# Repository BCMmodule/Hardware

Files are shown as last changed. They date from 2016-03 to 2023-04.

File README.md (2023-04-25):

# [BCM1 and BCS1](https://bcm-module.com)
Design and Document files for the BCMmodules BCM1 and BCS1 based on BeagleBone Black from [BeagleBoard.org](http://beagleboard.org). Please check out our [FAQ](https://github.com/BeagleCore/Hardware/wiki/FAQ) for questions and answers.

## BCM1 Contents
- Altium library
- Assembly Drawings
- BOM
- Footprint Drawing
- Gerber files
- Pick & Place
- Schematic Prints
- Step file
- System Reference Manual

## BCS1 Contents
- Assembly Drawings
- BOM
- Gerber files
- Pick & Place
- Schematic Prints

## General Contents
- Documentation
- Test Summary

Except where otherwise noted, licensed under a [Creative Commons Attribution-Share Alike 3.0 license](https://creativecommons.org/licenses/by-sa/3.0/). All derivative works are to be attributed to Gerald Coley of [BeagleBoard.org](http://beagleboard.org).

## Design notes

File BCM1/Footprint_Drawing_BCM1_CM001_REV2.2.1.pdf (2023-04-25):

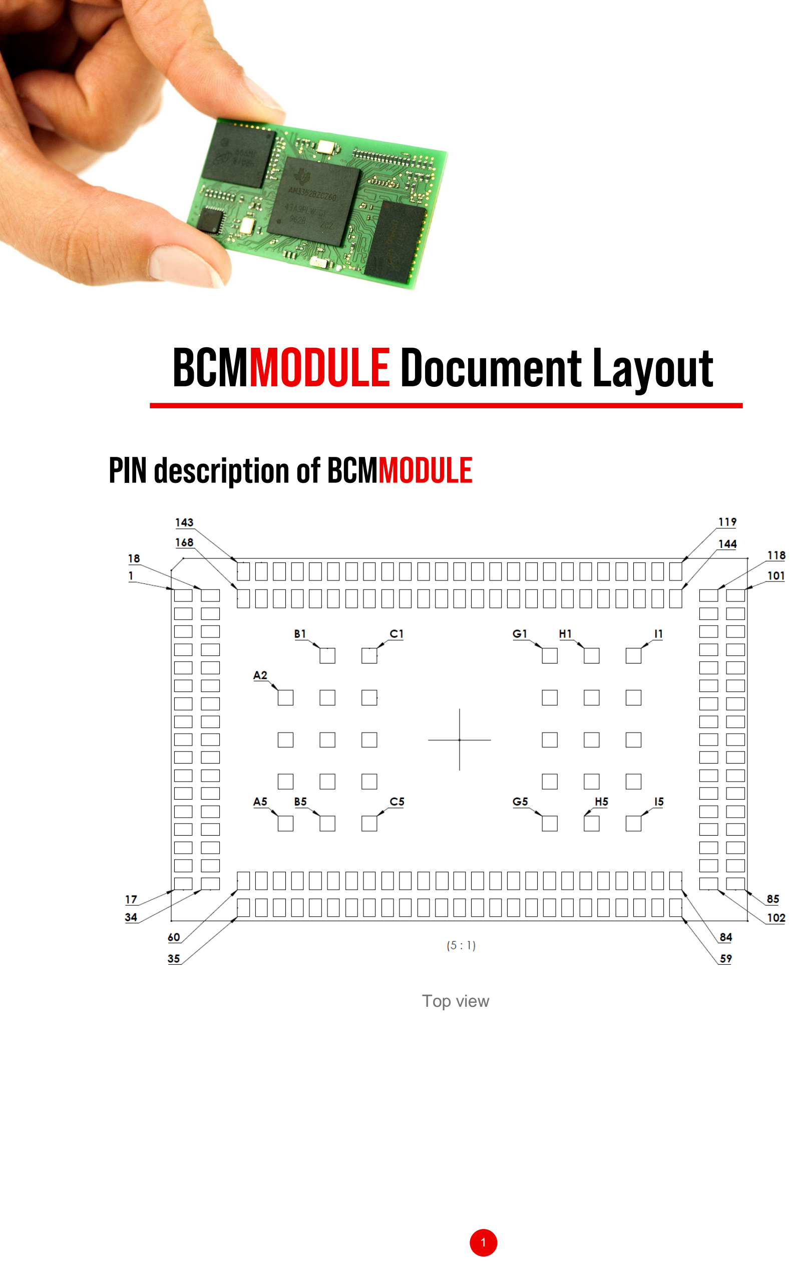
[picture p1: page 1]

1

## BCMMODULE Document Layout

PIN description of BCMMODULE

Top view

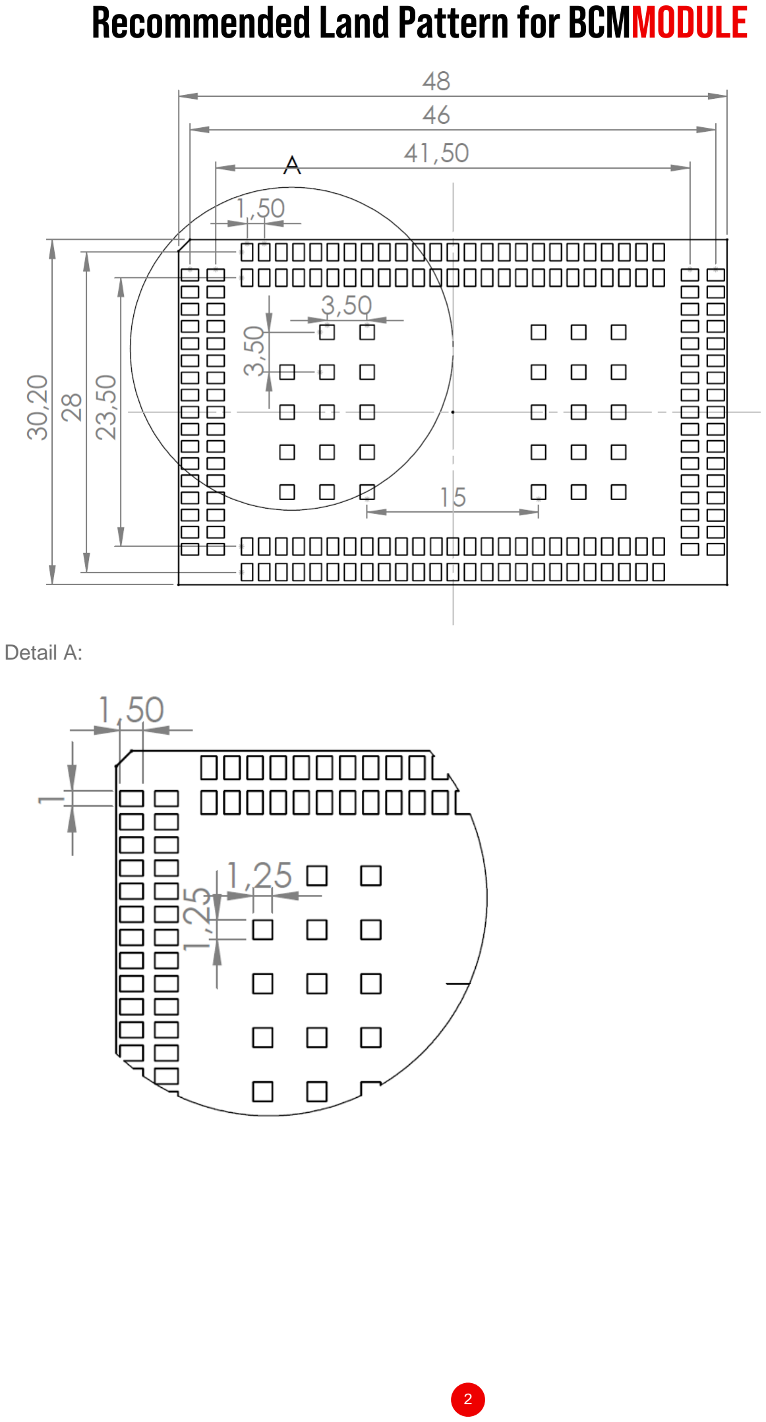
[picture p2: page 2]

2

Recommended Land Pattern for BCMMODULE

Detail A:

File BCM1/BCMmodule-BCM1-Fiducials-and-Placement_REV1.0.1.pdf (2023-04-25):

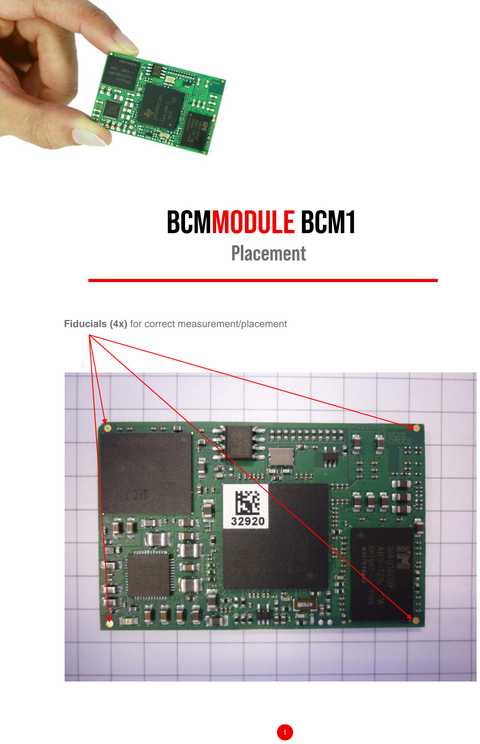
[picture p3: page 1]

# BCMMODULE BCM1

# Placement

Fiducials (4x) for correct measurement/placement

1

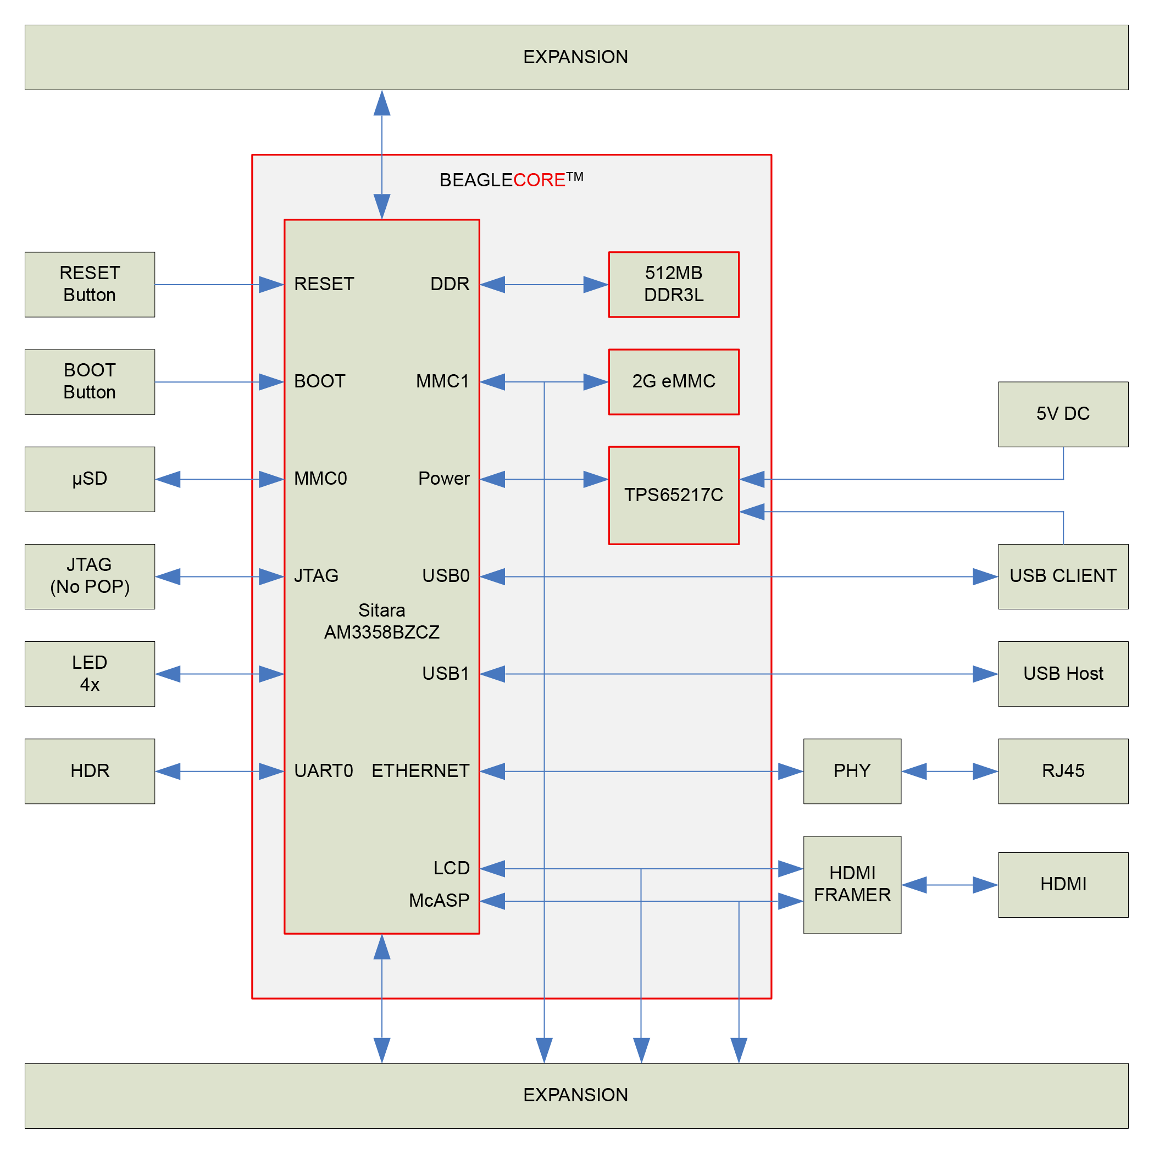
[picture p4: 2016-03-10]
BCM1/BeagleCore_BCM1_Block-Diagram.png

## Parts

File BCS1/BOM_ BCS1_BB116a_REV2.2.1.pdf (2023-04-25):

# Bill of Materials

Project: | BB116_V2.PrjPcb
Variant: | BB116a
Revision: | 2.2
Creation Date: | 21.07.2016 15:19:48
Bearbeiter: | Mierau
Art-Nr. | Quantity Designator | | Value | Description | Hersteller | Bestellbezeichnung | Footprint | S/T | Hersteller1 | Bestellbezeichnung1 | Lieferant
08.0002.0001 | 15 | C27, C29, C30, C35, C36, C131, C132, C135, C145, C147, C149, C150, C154, C155, C159 | 0.1uF/16V_02 | Capacitor 0402 16V Y5V | | | CC1005-0402 | SMD | Multicomp | MCCA000051
08.0001.0091 | 1 | C34 | 100uF/6.3V_121 0 | Capacitor 1210; 6.3V | Murata | GRM32ER60J107ME20 | CC3225-1210 | SMD
08.0001. | 2 | C133, C153 | 10uF/6V3_03 | Capacitor 0603 6V3; 10%, X5R | | | CC1608-0603 | SMD
08.0002.0011 | 1 | C134 | 1uF/10V_02 | Capacitor 0402 10V, X5R | | | CC1005-0402 | SMD
08.0002. | 1 | C136 | 470pF_02 | Capacitor 0402; 50V X7R | | | CC1005-0402 | SMD
08.0001.0055 | 1 | C141 | 22nF | Capacitor 0805; 50V; 10% | | | CC2012-0805 | SMD
08.0002.00__ | 2 | C142, C143 | 30pF/50V_02 | Capacitor 0402 50V Y5V | | | CC1005-0402 | SMD
08.0002. | 6 | C144, C146, C148, C151, C200, C201 | 2.2uF/6V3_02 | Capacitor 0402; 6V3; X5R | | | CC1005-0402 | SMD
08.0002.0___ | 16 | C156, C157, C160, C161, C162, C163, C164, C165, C166, C167, C168, C169, C170, C171, C172, C173 | 47pF/16V_02 | Capacitor 0402; 16V; X7R | | | CC1005-0402 | SMD
05.0101.00__ | 1 | D8 | RB751V40 | DIODE SCHOTTKY 40V 120MA SOD323 | NXP Semiconductors | RB751V40 | SOD323 | SMD
05.0701.0009 | 2 | DA6, DA7 | TPD4EUSB30_N P | Diode Array TVS, for USB3.0; 4fach, N und P getauscht | TI, NXP | IP4283CZ10-TBA | TPD4EUSB30 | SMD | | TPD4EUSB30DQAR
05.0701.00__ | 2 | DA9, DA10 | TPD4S012 | Diode Array TVS, for USB2.0 TypB; 4fach | TI | TPD4S012 | SON6 | SMD
04.0501.00__ | 1 | IC6 | 74LVC1G74DP | Dual D-Type Positive-Edge-Triggered Flip-Flop with Set and Reset | NXP | 74LVC1G74DP | TSSOP8 - 3x3 | SMD | | | Arrow
04.0601.00__ | 1 | IC8 | TPS2051B | Current-Limited PowerSwitch | ti | TPS2051BDGNR | DGN-MSOP8+1 | SMD
04.0601.00__ | 1 | IC11 | TDA19988 | DP to HDMI ESD, Level Shifter | NXP | TDA19988BHN/C1 | HVQFN64+EP_N | SMD
04.0601.00__ | 1 | IC14 | LAN8710A | Small Footprint MII/RMII 10/100 Ethernet Transceiver with HP Auto-MDIX and flexPWR® Technology | SMSC-Microchip | LAN8710A-EZK | QFN32+EP | SMD
04.0501.0041 | 1 | IC15 | 74LVC2G241DP | dual buffer/line driver; 3-state, 5V-tolerant | NXP | 74LVC2G241DP | TSSOP8 - 3x3 | SMD | | | Arrow
12.0501. | 4 | L3, L4, L7, L8 | 150L | Inductor 120 Ohm Ferrite 0805, 800mA | Laird-Signal Integrity Products | LI0805H151R-10 | CR2012-0805 | SMD | | | digikey,
12.0501.0011 | 2 | L5, L6 | WE-CNS-W | Stromkomp. Datenleitungsfilter WE-CNS-W, 90 Ohm | Würth Elektronik | 744231091 | WE-CNS_W -0805 | SMD | Murata | DLW21SN900SQ2L
22.07.2016 | Seite 1

# BCMMODULE

05.0401.0022 | 5 | LD1, LD2, LD3, LD4, LD5 | LEDgn_b_03 | Leuchtdiode bright grün 0603, RV(5mA)@3V3= 100OHM | Würth Elektronik | 150060VS75000 | CD1608-0603 | SMD | | | Würth Elektronik
| 6 | PM1, PM2, PM3, PM4, PM5, PM6 | PMR | Passer Markierung rund | | | PASSER_RUND
12.0601.00__ | 1 | Q3 | 25.0006MHz_CM 3225 | Quarz 25.0006MHz; CM3225 | Comtec Crystal | CM3225- 25.0006MHz | QUARZ CM3225 | SMD | Geyer | CM3225- 25.0006MHz | Comtec Crystal, Geyer
12.0601. | 1 | QO4 | 24.576MHz-V96 | Quarz Oszillator 24.576MHz; KXO-V96 | Geyer | KXO-V96 24.576MHz | QUARZ KXO-V96 | SMD | | | Geyer
09.0002. | 5 | R12, R71, R72, R73, R74 | 820R_02 | Resistor 0402 | | | CR1005-0402 | SMD
09.0002.0002 | 15 | R19, R20, R46, R47, R48, R49, R50, R51, R96, R137, R142, R149, R159, R160, R161 | 0R_02 | Resistor 0402 | | | CR1005-0402 | SMD
09.0002.0014 | 2 | R21, R167 | 33R_02 | Resistor 0402 | | | CR1005-0402 | SMD
09.0002.0017 | 3 | R23, R24, R25 | 4k75_02 | Resistor 0402 | | | CR1005-0402 | SMD
09.0002.0012 | 1 | R45 | 22R_02 | Resistor 0402 | | | CR1005-0402 | SMD
09.0002.0004 | 19 | R52, R53, R115, R116, R117, R118, R135, R145, R146, R147, R148, R150, R151, R152, R153, R154, R155, R157, R158 | 10k_02 | Resistor 0402 | | | CR1005-0402 | SMD
09.0001.0013 | 11 | R75, R125, R126, R127, R128, R129, R131, R133, R134, R138, R139 | 100R_02 | Resistor 0402 1% | | | CR1005-0402 | SMD
09.0002.00__ | 4 | R112, R113, R114, R119 | 1k5_02 | Resistor 0402 1/16W 1% | | | CR1005-0402 | SMD
09.0002.0016 | 4 | R120, R121, R122, R123 | 49R9_02 | Resistor 0402 | | | CR1005-0402 | SMD
09.0001.0158 | 2 | R130, R132 | 1k2_03_1% | Resistor 0603; 1% 1/16W | | | CR1608-0603 | SMD
09.0002.0015 | 1 | R141 | 1M_02 | Resistor 0402 | | | CR1005-0402 | SMD
09.0002.00__ | 1 | R143 | 10R_02 | Resistor 0402 | | | CR1005-0402 | SMD
09.0001.01__ | 1 | R144 | 12k1_02 | Resistor 0402; 1% | | | CR1005-0402 | SMD
09.0001.0286 | 1 | R163 | 0.02R_05 | Resistor Bauform 0805; 5% 1/4W; | | | CR2012-0805 | SMD
09.0002.0003 | 1 | R165 | 100k_02 | Resistor 0402 | | | CR1005-0402 | SMD
09.0002.0011 | 1 | R166 | 26k7_02 | Resistor 0402 | | | CR1005-0402 | SMD
99.0000.0___ | 1 | RT1 | MF-MSMF010 | resettable Fuse MF_MSMF 30V, 0,2A bei 23°C | BOURNS | MF-MSMF010 | FUSE-MF-MSMF | SMD
06.0001.00__ | 2 | T1, T2 | DDC114YU | 2 fach NPN m Widerständen Vceo=40V, Ic=0.1A | Rohm | DDC114YU | SOT363 | SMD
10.0100.00__ | 3 | TA1, TA2, TA3 | TA_C&K_KMR23 1 | Taster smd 1pol mm pitch, 4.6x2.8mm case | C&K | KMR231GLFS | TA_KMR2 | SMD
03.0100.0158 | 1 | XB3 | USB_R_WE | USB einfach RA Type A | Würth | 61400416021 | 61400416021 | THT | | | Würth
| 1 | XB4 | MINI-USB_B | USB MINI Typ B einfach 5pol. | Molex | 0513870530 | USB-MINI-B | SMD

03.0100.0301 | 1 | XB5 | J00-0065NL;RJ45+Ü +L | Buchse RJ45 mit Übertrager und LEDS | Pulse, Würth | J00-0065NL | RJ45+Ü+L | THT | 7499010211A
03.0101.00__ | 1 | XB6 | Micro-HDMI_Buchse_T ype D | micro HDMI Buchse SMT Type D | fci | 10118241-001RLF | Micro_HDMI_FCI_ SMT_Type D | SMT
0..0000.0... | 2 | XB8, XB9 | B2X23_THT | Buchsenleiste 46pol. IDC, vertikal 2.54mm pitch | Sullins Connector Solutions | PPPC232LFBN-RC | BU2X23 | THT | | Digi Key; S7126-ND,
03.0101.00.. | 1 | XB10 | MICRO SD_ALPS_R | MICRO SD Memory card connector push/push reverse mount ALPS (SCHA5B0200) | ALPS | SCHA5B0200 | Micro-SD-Card-Reverse Mount Conn-ALPS- | SMD
03.0__0.00__ | 1 | XS1 | ST1x2_PJ | DC-Power-Jack, 2mm Stift, 5A, THT,gew. | CUI | PJ-002AH | ST1X2THT-2mm-DC_WA | THT

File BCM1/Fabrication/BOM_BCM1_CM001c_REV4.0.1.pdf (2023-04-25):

# Bill of Materials

Project: | CM001_V4.PrjPcb
Variant: | CM001c
Revision: | 4.0
Creation Date: | 07.09.2018 14:06:05
Bearbeiter: | Mierau
Art-Nr. | QuanDesignator | | Value | Description | Hersteller | Bestellbezeichnung | Footprint | S/T | Hersteller1 | Bestellbezeichnung1 | Lieferant
08.0001.0___ | 23 | C1, C2, C4, C7, C8, C9, C10, C11, C12, C13, C14, C15, C39, C40, C41, C55, C62, C77, C95, C96, C118, C122, C126 | 10uF_03_10V_X 7R | Capacitor 0603 10uF 10V X7R | | | CC1608-0603 | SMD
08.0002.0___ | 82 | C3, C20, C28, C31, C33, C37, C38, C42, C43, C44, C45, C46, C47, C48, C49, C50, C51, C52, C53, C54, C56, C57, C58, C59, C60, C61, C63, C64, C65, C66, C67, C68, C69, C70, C71, C72, C73, C74, C75, C76, C78, C79, C80, C81, C82, C83, C84, C85, C86, C87, C88, C92, C93, C94, C97, C98, C99, C100, C101, C102, C103, C105, C107, C108, C109, C110, C111, C112, C113, C114, C115, C116, C117, C119, C120, C121, C124, C127, C128, C129, C130, C158

0.1uF/6V3_01_X
7R
Capacitor 0201 6,3V X7R | any | CC0603-0201 | SMD
08.0002. | 4 | C16, C18, C24, C125 | 2.2uF/6V3_02_X 7R | Capacitor 0402 6V3 X7R | CC1005-0402 | SMD
08.0002.___ | 1 | C17 | 2.2uF/10V_02_X 7R | Capacitor 0402 10V X7R | CC1005-0402 | SMD
08.0002. | 1 | C19 | 470pF_02 | Capacitor 0402 50V X7R | CC1005-0402 | SMD
08.0002.0037 | 4 | C21, C22, C25, C26 | 18pF_02 | Capacitor 0402 50V NPO | CC1005-0402 | SMD
08.0002.0009 | 2 | C32, C123 | 1nF/50V_02 | Capacitor 0402 X7R 50V | CC1005-0402 | SMD
08.0002.0030 | 3 | C89, C90, C91 | 1uF/10V_01 | Capacitor 0201 10V X6S | CC0603-0201 | SMD
08.0002.0011 | 1 | C104 | 1uF/10V_02 | Capacitor 0402 10V X5R | CC1005-0402 | SMD

# BCMMODULE

08.0002.0041 | 1 | C106 | 1uF/25V_02_X6 S | Capacitor 0402 25V X6S | | | CC1005-0402 | SMD
08.0002.0___ | 1 | C152 | 0.1uF/16V_02_X 7R | Capacitor 0402 16V X7R | | | CC1005-0402 | SMD | muRata | GCM188R70J225KE22D
04.0501.00__ | 1 | IC3 | SN74LVC1G06D CK | Single buffer/line driver, 5V-tolerant Input, Open collector, SOT353(SC70) | TI | SN74LVC1G06DCK | SOT353 | SMD | | | Arrow
04.0701. | 1 | IC5 | AM3358BZCZA1 00 | Cortex A8 Processor 15x15_industriell | Texas Instruments | AM3358BZCZA100 | BGA324_RM0.8_1 5x15 | SMD | | | digikey
04.0701. | 1 | IC7 | CAT24C32C5CT R | Serial EEPROM; 2-wire, 8192 x 8 bits | ON SEMI | CAT24C32C5CTR | WLCSP5 | SMD
04.0701.0145 | 1 | IC12 | DDR3L-800-SDRAM-4G-256Mx16_i | DDR3L 800MHz SDRAM; 4Giga 256M x 16, industrial | Intelligent Memory | IM4G16D3FABG-125I | BGA96_T9_P8_9 X14 | SMD | | | Memphis
04.0701. | 1 | IC13 | eMMC-4GB | Flash Card 4G-byte 3.3V MultiMedia Card 153-Pin WFBGA | Hynix | H26M31001HPR | BGA153_P14_P5_ 11P5X13 | SMD | Kingston | KE4CN2H5A-A58 | memphis
04.0501.0057 | 1 | IC16 | 74LVC1G07DCK | Single Buffer/Driver With Open-Drain Output SOT353 (SC70) | TI | 74LVC1G07DCK | SOT353 | SMD | | | Arrow
12.0501. | 3 | L1, L2, L3 | 2.2uH_20 | Inductor 2520; 2,2uH; 1,3A | MURATA | LQM2HPN2R2MG0L | CR9879-2520 | SMD
12.0501. | 3 | L4, L5, L6 | 150L | Inductor 150 Ohm Ferrite 0805, 800mA | Laird-Signal Integrity Products | LI0805H151R-10 | CR2012-0805 | SMD | | | digikey,
05.0401.0022 | 1 | LD1 | LEDgn_b_03 | Leuchtdiode bright grün 0603, RV(5mA)@3V3= 100OHM | Würth Elektronik | 150060VS75000 | CD1608-0603 | SMD | | | Würth Elektronik
| 4 | PM1, PM2, PM3, PM4 | PMR | Passer Markierung rund | | | PASSER_RUND
09.0002.0003 | 1 | R1 | 100k_02 | Resistor; 0402; 1% | | | CR1005-0402 | SMD
09.0002.0028 | 3 | R3, R4, R97 | 1k5_02 | Resistor; 0402; 1% | | | CR1005-0402 | SMD
09.0002.0002 | 9 | R5, R6, R7, R8, R27, R29, R30, R162, R165 | 0R_02 | Resistor; 0402; 5% | | | CR1005-0402 | SMD
09.0002.0023 | 1 | R10 | 470k_02 | Resistor; 0402; 1% | | | CR1005-0402 | SMD
09.0002. | 1 | R11 | 280k_02 | Resistor; 0402; 1% | | | CR1005-0402 | SMD
09.0002. | 1 | R12 | 820R_02 | Resistor; 0402; 1% | | | CR1005-0402 | SMD
09.0002.0004 | 17 | R14, R54, R96, R98, R100, R101, R102, R103, R104, R105, R106, R107, R108, R109, R110, R111, R156 | 10k_02 | Resistor; 0402; 1% | | | CR1005-0402 | SMD
09.0002.0015 | 1 | R17 | 1M_02 | Resistor; 0402; 1% | | | CR1005-0402 | SMD
09.0002.0014 | 2 | R18, R28 | 33R_02 | Resistor; 0402; 1% | | | CR1005-0402 | SMD
09.0002.0016 | 1 | R22 | 49R9_02 | Resistor; 0402; 1% | | | CR1005-0402 | SMD
09.0002.0017 | 3 | R26, R163, R164 | 4k75_02 | Resistor; 0402; 1% | | | CR1005-0402 | SMD
09.0002.0070 | 16 | R57, R65, R66, R67, R68, R80, R82, R83, R84, R85, R86, R87, R88, R89, R94, R95 | 100k_01 | Resistor 0201, 1/20W | | | CR0603-0201 | SMD
09.0002.0071 | 1 | R99 | 240R_02 | Resistor; 0402; 1% | | | CR1005-0402 | SMD
04.0901. | 1 | SR1 | TPS65217DRSL | TPS65217x Single-Chip PMIC for Battery-Powered Systems | TI | TPS65217DRSL | RSL48+1_TI_TPS | SMD
04.0901. | 1 | SR2 | TL5209 | IC LDO VOLT REG 500MA 8-SOIC | TI | TL5209DR | SO8 | SMD | | | Arrow

12.0601.00__ | 1 | Y1 | 32.768kHz_i | Quarz; 3,2x1,5mm, -40°C bis 85°C | Epson | FC-135 32.7680KA-A3 | CM3215 | SMD
12.0601.0029 | 1 | Y2 | 24MHz_CM3225 _i | Quarz; 3,2x2,5mm, 20pF, -40°C bis 85°C | Fox Electronics | FQ3225BR-24.000 | QUARZ CM3225 | SMD | Comtec Crystals | A024000000CIFBPN43D B | Digikey

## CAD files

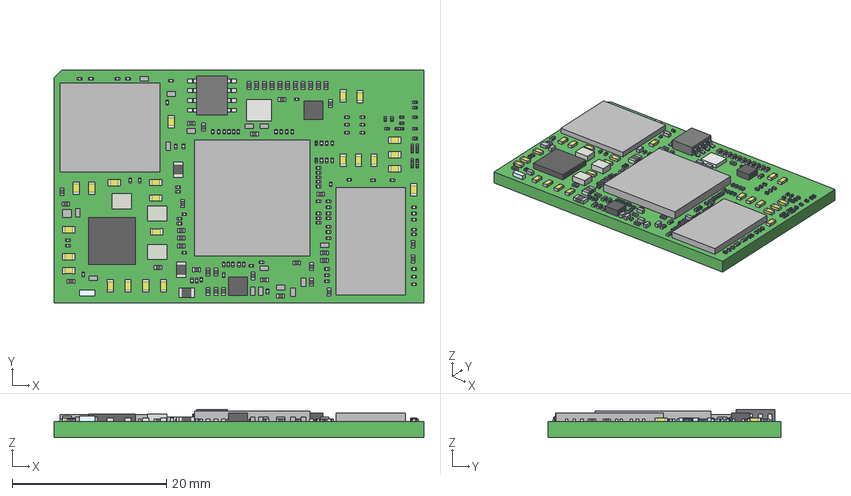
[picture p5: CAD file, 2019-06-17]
BCM1/Fabrication/BCM1_CM001_REV4.0.step
48.0 x 30.2 x 3.69 mm
Extruded x 373
CR_0402 x 42
CR_0805 x 3
CC_0603 x 23

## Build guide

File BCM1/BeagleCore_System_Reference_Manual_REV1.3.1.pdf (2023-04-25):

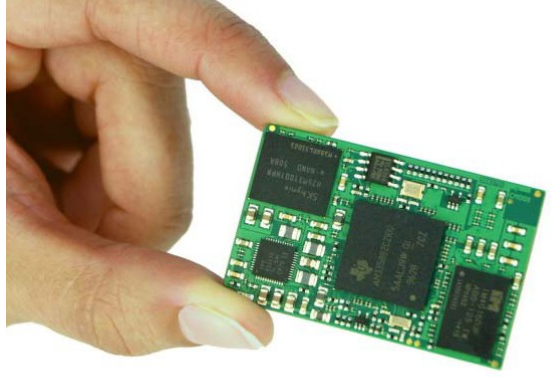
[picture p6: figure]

BCMMODULE BCM1 | 1

# BCMMODULE BCM1

# System Reference Manual

### Revision 1.3

# Disclaimer

The design materials referred to in this document are based on the BeagleBone Black and are neither supported nor do they constitute a reference design. If you are looking for support, please join the BeagleBoard Community over at BeagleBoard.org/discuss.

There is no warranty for the design materials, to the extent permitted by applicable law. Except when otherwise stated in writing the copyright holders and/or other parties provide the design materials “as is” without warranty of any kind, either expressed or implied, including, but not limited to, the implied warranties of merchantability and fitness for a particular purpose. The entire risk as to the quality and performance of the design materials is with you. In no event shall the authors or copyright holders be liable for any claim,
damages or other liability, whether in an action of contract, tort or otherwise, arising from, out of or in connection with the design material or the use or other dealings in the design materials. Should the design materials prove defective, you assume the cost of all necessary servicing, repair or correction.

The user assumes all responsibility and liability for proper and safe handling of the goods. Further, the user indemnifies BCMmodule from all claims arising from the handling or use of the goods. Due to the open construction of the product, it is the user’s responsibility to take any and all appropriate precautions with regard to electrostatic discharge.

Except to the extent of the indemnity set forth above, neither party shall be liable to the other for any indirect, special, incidental, or consequential damages. BCMmodule currently deals

2

with a variety of customers for products, and therefore our arrangement with the user is not exclusive. BCMmodule assumes no liability for applications assistance, customer product design, software performance, or infringement of patents or services described herein.

Please read the System Reference Manual and, specifically, the Warnings and Restrictions notice in the User’s Guide prior to handling the product. This notice contains important safety information about temperatures and voltages.

For additional information, please visit bcm-module.com.

Postal Address:

## iesy GmbH

Darmcher Grund 22
58540 Meinerzhagen
Germany

# Introduction

This document is the System Reference Manual for BCM1. It is intended as a guide to assist anyone purchasing or who are considering purchasing the board to understand the overall system design and the features of the BCM1. It can also be used as a reference for the design for those who are implementing this design into their own product.

This design is subject to change without notice as we will work to keep improving the design as the product matures.

This design is subject to change without notice as we will work to keep improving the design as the product matures.

# Known Issues

For an up to date list of all known issues per revision, please refer to the BCMmodule GitHub repository and the issues listed there: https://github.com/BCMmodule/Hardware/issues.

# BCMMODULE BCM1

3

# Contents

# BCMMODULE BCM1

4

# 1. What is BCMMODULE?

The BCM1 is a miniaturized computer module for industrial or commercial applications covering all core features of BeagleBone Black. It is designed to address the Open Source Community, early adopters, and anyone interested in a low cost ARM Cortex A8 based processor. It enables users to design their own embedded devices while remaining a maximum compatibility with the BeagleBone Black.

# 2. Features

This section covers the specifications of the BCM1.

### - Dimensions (WDH): 48 mm × 31 mm × 3,5 mm

### - Processor: Texas Instruments AM335x Cortex-A8 “Sitara”

### - Clock rate: 1.0GHz

### - Memory: 512 MB DDR3

### - Flash: 4 GB 8-bit eMMC

### - Temperature range: 0…60°C (optionally: -40…85°C)

- Operating: 10 to 90% r. H. non cond.
Storage: 5 to 95% r. H. non cond.

### - Supported interfaces / extensions:

### o 1 × RGMII Interface for 10/100/1000 Mbit LAN

### o 2 × USB 2.0 Host / Client

### o 1 × SDIO (for SD memory cards)

### o 1 × UART / 1 × JTAG (for debugging)

o up to 59 × GPIO for HDMI, CAN, I2C, etc.

For further details we would like to refer to the latest documentation for BeagleBone Black available at http://beagleboard.org/static/beaglebone/latest/Docs/Hardware/.

# BCMMODULE BCM1

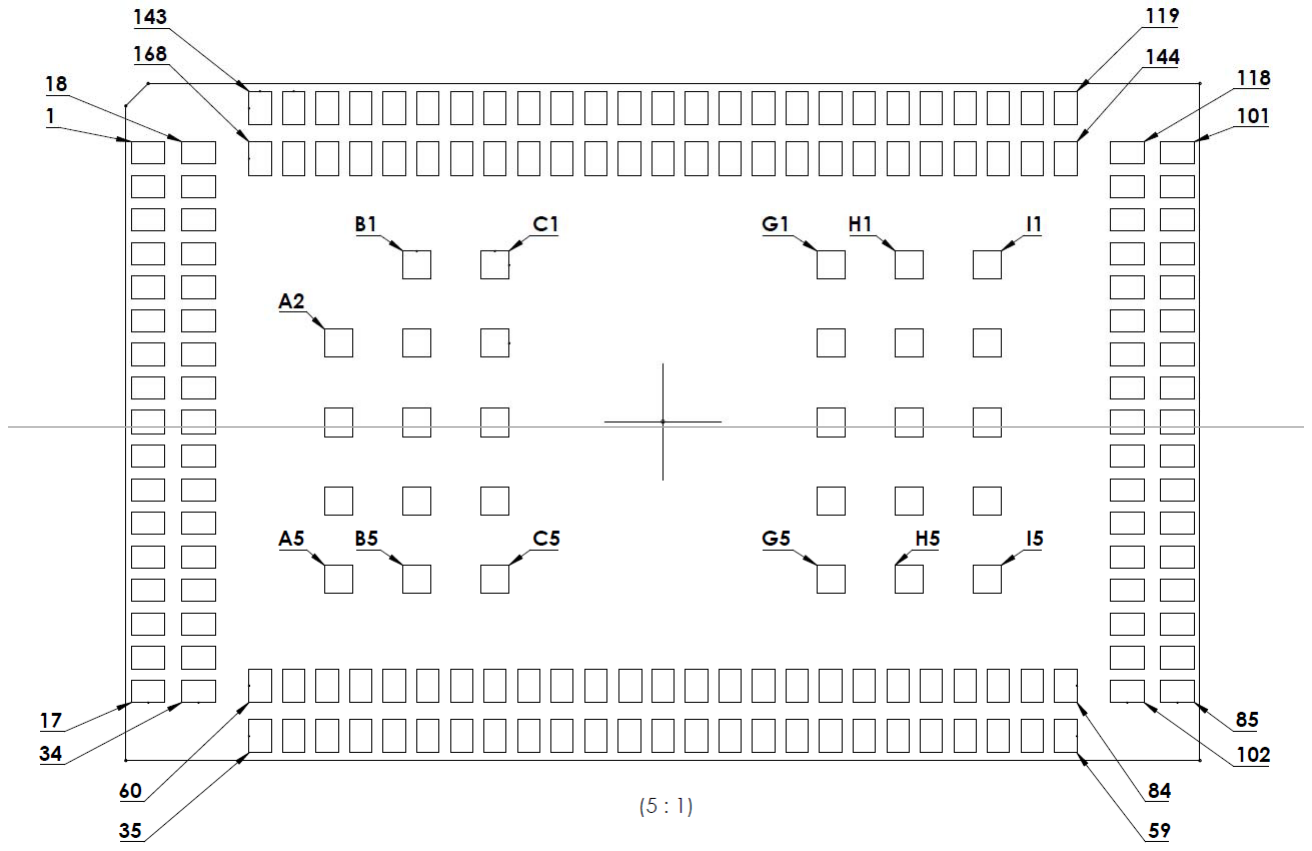
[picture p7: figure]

5

# 3. Specifications

# 3.1 Pin-signals Graphic Overview

This section covers the pin-signals of the BCM1 and provides descriptions of the major components and interfaces that make up the BCM1.

Img. 1: Pin-signals for BCM1 (top view)

# 3.2 Pin-signals Table

# BCMMODULE BCM1

6

Pin on BGA | Transfer-Signal on BGA | from Pin AM3358BZCZ100 | from Pin TPS65217CRSLR | comment
1 | USB0_D_P | N17
2 | USB0_D_N | N18
3 DGND
4 | MII1_RXD2 | L16 | | GMII1_RXD2/UART3_TXD/RGMII1_RD2/MMC0_DAT4/MMC1_DAT3/ UART1_RIN/MCASP0_AXR1/GPIO2_19
5 | MII1_RXD3 | L17 | | GMII1_RXD3/UART3_RXD/RGMII1_RD3/MMC0_DAT5/MMC1_DAT2/ UART1_DTRN/MCASP0_AXR0/GPIO2_18
6 | MII1_RXCLK | L18 | | GMII1_RXCLK/UART2_TXD/RGMII1_RCLK/MMC0_DAT6/MMC1_DAT1/ UART1_DSRN/MCASP0_FSX/GPIO3_10
7 | MII1_TXD1 | K16 | | GMII1_TXD1/RMII1_TXD1/RGMII1_TD1/MCASP1_FSR/MCASP1_AXR1/ EQEP0A_IN/MMC1_CMD/GPIO0_21
8 | MII1_TXD3 | J18 | | GMII1_TXD3/DCAN0_TX/RGMII1_TD3/UART4_RXD/MCASP1_FSX/ MMC2_DAT1/MCASP0_FSR/GPIO0_16
9 | MII1_RXDV | J17 | | GMII1_RXDV/LCD_MEMORY_CLK/RGMII1_RCTL/UART5_TXD/ MCASP1_ACLKX/MMC2_DAT0/MCASP0_ACLKR/GPIO3_4
10 | MII1_TXEN | J16 | | GMII1_TXEN/RMII1_TXEN/RGMII1_TCTL/TIMER4/MCASP1_AXR0/ EQEP0_INDEX/MMC2_CMD/GPIO3_3
11 | MII1_REFCLK | H18 | | RMII1_REFCLK/XDMA_EVENT_INTR2/SPI1_CS0/UART5_TXD/ MCASP1_AXR3/MMC0_POW/MCASP1_AHCLKX/GPIO0_29
12 | MII1_COL | H16 | | GMII1_COL/RMII2_REFCLK/SPI1_SCLK/UART5_RXD/MCASP1_AXR2/ MMC2_DAT3/MCASP0_AXR2/GPIO3_0
13 | BKL_ISET2 | | 36
14 | BKL_ISET1 | | 35
15 | BKL_L4 | | 37
16 | BKL_FB_WLED | | 38
17 DGND
18 DGND
19 | MDIO_DATA | M17 | | MDIO_DATA/TIMER6/UART5_RXD/UART3_CTSN/MMC0_SDCD/ MMC1_CMD/MMC2_CMD/GPIO0_0
20 | MDIO_CLK | M18 | | MDIO_CLK/TIMER5/UART5_TXD/UART3_RTSN/MMC0_SDWP/ MMC1_CLK/MMC2_CLK/GPIO0_1
21 | MII1_RxD0 | M16 | | GMII1_RXD0/RMII1_RXD0/RGMII1_RD0/MCASP1_AHCLKX/ MCASP1_AHCLKR/MCASP1_ACLKR/MCASP0_AXR3/GPIO2_21
22 | MII1_RxD1 | L15 | | GMII1_RXD1/RMII1_RXD1/RGMII1_RD1/MCASP1_AXR3/MCASP1_FSR/ EQEP0_STROBE/MMC2_CLK/GPIO2_20

# BCMMODULE BCM1

7

Pin on BGA | Transfer-Signal on BGA | from Pin AM3358BZCZ100 | from Pin TPS65217CRSLR | comment
23 | MII1_TXCLK | K18 | | GMII1_TXCLK/UART2_RXD/RGMII1_TCLK/MMC0_DAT7/MMC1_DAT0/ UART1_DCDN/MCASP0_ACLKX/GPIO3_9
24 | MII1_TxD0 | K17 | | GMII1_TXD0/RMII1_TXD0/RGMII1_TD0/MCASP1_AXR2/ MCASP1_ACLKR/EQEP0B_IN/MMC1_CLK/GPIO0_28
25 | MII1_TxD2 | K15 | | GMII1_TXD2/DCAN0_RX/RGMII1_TD2/UART4_TXD/MCASP1_AXR0/ MMC2_DAT2/MCASP0_AHCLKX/GPIO0_17

26 DGND
27 | MII1_RXERR | J15 | | GMII1_RXERR/RMII1_RXERR/SPI1_D1/I2C1_SCL/MCASP1_FSX/ UART5_RTSN/UART2_TXD/GPIO3_2
28 | MII1_CRS_DV | H17 | | GMII1_CRS/RMII1_CRS_DV/SPI1_D0/I2C1_SDA/MCASP1_ACLKX/ UART5_CTSN/UART2_RXD/GPIO3_1

29 DGND
30 | BKL_ISINK2 | | 33
31 | BKL_ISINK1 | | 34
32 | I2C0_SCL | C16 | 28 | I2C0_SCL/TIMER7/UART2_RTSN/ECAP1_IN_PWM1_OUT////GPIO3_6
33 | I2C0_SDA | C17 | 27 | I2C0_SDA/TIMER4/UART2_CTSN/ECAP2_IN_PWM2_OUT////GPIO3_5
34 DGND
35 | UART4_TXD | U17 | GPMC_WPN/GMII2_RXERR/GPMC_CSN5/RMII2_RXERR/MMC2_SDCD/ PR1_MDIO_MDCLK/UART4_TXD/GPIO0_31
36 | UART4_RXD | T17 | GPMC_WAIT0/GM112_CRS/GPMC_CSN4/RMII2_CRS_DV/ MMC1_SDCD/PR1_MII1_RXDV/UART4_RXD/GPIO0_30
37 | GPIO1_28 | U18 | GPMC_BE1N/GMII2_COL/GPMC_CSN6/MMC2_DAT3/GPMC_DIR/ PR1_MII1_RXLINK/MCASP0_ACLKR/GPIO1_28
38 | EHRPWM1A | U14 | GPMC_A2/GMII2_TXD3/RGMII2_TD3/MMC2_DAT1/GPMC_A18/ PR1_MII1_TXD2/EHRPWM1A/GPIO1_18
39 | EHRPWM1B | T14 | GPMC_A3/GMII2_TXD2/RGMII2_TD2/MMC2_DAT2/GPMC_A19/ PR1_MII1_TXD1/EHRPWM1B/GPIO1_19
40 | MMC0_DAT3 | F17 | MMC0_DAT3/GPMC_A20/UART4_CTSN/TIMER5/UART1_DCDN/ PR1_PRU0_PRU_R30_8/PR1_PRU0_PRU_R31_8/GPIO2_26
41 | MMC0_DAT1 | G15 | MMC0_DAT1/GPMC_A22/UART5_CTSN/UART3_RXD/UART1_DTRN/ PR1_PRU0_PRU_R30_10/PR1_PRU0_PRU_R31_10/GPIO2_28
42 | MMC0_CD | C15 | SPI0_CS1/UART3_RXD/ECAP1_IN_PWM1_OUT/MMC0_POW/ XDMA_EVENT_INTR2/MMC0_SDCD/EMU4/GPIO0_60

# BCMMODULE BCM1

8

Pin on BGA | Transfer-Signal on BGA | from Pin AM3358BZCZ100 | from Pin TPS65217CRSLR | comment
43 XDMA_EVENT_INT | R0 | A15 | | EVENT_INTR0/TIMER4/CLKOUT1/SPI1_CS1/PR1PRU1R31_16/EMU2/ GPIO0_19
44 | UART0_CTS# | E18 | | Reserved for future use
45 | UART0_RTS# | E17 | | Reserved for future use
46 | UART0_TX | E16 | | UART0_TXD/SPI1_CS1/DCAN0_RX/I2C2_SCL/ECAP1_IN_PWM1_OUT/ PR1_PRU1_PRU_R30_15/PR1_PRU1_PRU_R31_15/GPIO1_11
47 | UART0_RX | E15 | | UART0_RXD/SPI1_CS0/DCAN0_TX/I2C2_SDA/ECAP2_IN_PWM2_OUT/ PR1_PRU1_PRU_R30_14/PR1_PRU1_PRU_R31_14/GPIO1_10
48 | SYS_RESETn | A10
49 | I2C1_SDA | B16 | | SPI0_D1/MMC1_SDWP/I2C1_SDA/EHRPWM0_TRIPZONE_INPUT/ PR1_UART0_RXD/PR1_EDIO_DATA_IN0/PR1_EDIO_DATA_OUT0/GPIO0_4
50 | I2C1_SCL | A16 | | SPI0_CS0/MMC2_SDWP/I2C1_SCL/EHRPWM0_SYNCI_O/ PR1_UART0_TXD/PR1_EDIO_DATA_IN1/PR1_EDIO_DATA_OUT1/GPIO0_5
51 | JTAG_EMU1 | B14
52 | JTAG_TCK | A12
53 | JTAG_TDO | A11
54 | JTAG_TRSTn | B10
55 | GNDA_ADC | A9
56 | AIN6 | A8
57 | AIN4 | C8
58 | AIN2 | B7
59 | AIN0 | B6
60 | BAT1 | | 4, 5
61 | BAT_SENSE | | 6
62 | BAT_TS | | 11
63 | PWR_BUT | | 25
64 | MMC0_CMD | G18 | | MMC0_CMD/GPMC_A25/UART3_RTSN/UART2_TXD/DCAN1_RX/ PR1_PRU0_PRU_R30_13/PR1_PRU0_PRU_R31_13/GPIO2_31
65 | MMC0_CLKO | G17 | | MMC0_CLK/GPMC_A24/UART3_CTSN/UART2_RXD/DCAN1_TX/ PR1_PRU0_PRU_R30_12/PR1_PRU0_PRU_R31_12/GPIO2_30
66 | MMC0_DAT2 | F18 | | MMC0_DAT2/GPMC_A21/UART4_RTSN/TIMER6/UART1_DSRN/ PR1_PRU0_PRU_R30_9/PR1_PRU0_PRU_R31_9/GPIO2_27

# BCMMODULE BCM1

9

Pin on BGA | Transfer-Signal on BGA | from Pin AM3358BZCZ100 | from Pin TPS65217CRSLR | comment
67 | MMC0_DAT0 | G16 | | MMC0_DAT0/GPMC_A23/UART5_RTSN/UART3_TXD/UART1_RIN/ PR1_PRU0_PRU_R30_11/PR1_PRU0_PRU_R31_11/GPIO2_29
68 | GPIO0_7SRC | C18 | | ECAP0_IN_PWM0_OUT/UART3_TXD/SPI1_CS1/ PR1_ECAP0_ECAP_CAPIN_APWM_O/SPI1_SCLK/MMC0_SDWP/ XDMA_EVENT_INTR2/GPIO0_7
69 | UART2_RXD | A17 | | SPI0_SCLK/UART2_RXD/I2C2_SDA/EHRPWM0A/PR1_UART0_CTS_N/ PR1_EDIO_SOF/EMU2/GPIO0_2
70 | UART2_TXD | B17 | | SPI0_D0/UART2_TXD/I2C2_SCL/EHRPWM0B/PR1_UART0_RTS_N/ PR1_EDIO_LATCH_IN/EMU3/GPIO0_3
71 | I2C2_SDA | D18 | | UART1_CTSN/TIMER6/DCAN0_TX/I2C2_SDA/SPI1_CS0/PR1_UART0_CTS_ N/PR1_EDC_LATCH0_IN/GPIO0_124
72 | I2C2_SCL | D17 | | UART1_RTSN/TIMER5/DCAN0_RX/I2C2_SCL/SPI1_CS1/PR1_UART0_RTS_ N/PR1_EDC_LATCH1_IN/GPIO0_13
73 | UART1_RXD | D16 | | UART1_RXD/MMC1_SDWP/DCAN1_TX/I2C1_SDA//PR1_UART0_RXD/ PR1_PRU1_PRU_R31_16/GPIO0_14
74 | UART1_TXD | D15 | | UART1_TXD/MMC2_SDWP/DCAN1_RX/I2C1_SCL//PR1_UART0_TXD/ PR1_PRU0_PRU_R31_16/GPIO0_15

75 DGND
76 | CLKOUT_SRC | D14 | | EVENT_INTR1/TCLKIN/CLKOUT2/TIMER7/PR1PRU0_PRUR31_16/ EMU3/GPIO0_20
77 | JTAG_EMU0 | C14
78 | JTAG_TDI | B11
79 | JTAG_TMS | C11
80 | GNDA_ADC | A8
81 | VDD_ADC | B9 (über R27)
82 | AIN5 | B8
83 | AIN3 | A7
84 | AIN1 | C7
85 | GPIO3_18 | B12 | MCASP0_ACLKR/EQEP0A_IN/MCASP0_AXR2/MCASP1_ACLKX/ MMC0_SDWP/PR1_PRU0_PRU_R30_4/PR1_PRU0_PRU_R31_4/GPIO3_18
86 | GPIO3_19 | C13 | MCASP0_FSR/EQEP0B_IN/MCASP0_AXR3/MCASP1_FSX/EMU2/ PR1_PRU0_PRU_R30_5/PR1_PRU0_PRU_R31_5/GPIO3_19

# BCMMODULE BCM1

10

Pin on BGA | Transfer-Signal on BGA | from Pin AM3358BZCZ100 | from Pin TPS65217CRSLR | comment
87 | GPIO3_20 | D13 | | MCASP0_AXR1/EQEP0_INDEX//MCASP1_AXR0/EMU3/ PR1_PRU0_PRU_R30_6/PR1_PRU0_PRU_R31_6/GPIO3_20
88 | GPIO3_21 | A14 | | MCASP0_AHCLKX/EQEP0_STROBE/MCASP0_AXR3/MCASP1_AXR1/ EMU4/PR1_PRU0_PRU_R30_7/PR1_PRU0_PRU_R31_7/GPIO3_21
89 | USB1_ID | P17
90 DGND
91 | USB1_D_P | R17
92 | USB1_D_N | R18
93 | USB1_Ocn | T16 | | GPMC_A10/GMII2_RXD1/RGMII2_RD1/RMII2_RXD1/GPMC_A26/ PR1_MII1_CRS/MCASP0_AXR0/GPIO1_26
94 | LCD_DATA0 | R1 | | LCD_DATA0/GPMC_A0//EHRPWM2A//PR1_PRU1_PRU_R30_0/ PR1_PRU1_PRU_R31_0/GPIO2_6
95 | LCD_DATA2 | R3 | | LCD_DATA2/GPMC_A2//EHRPWM2_TRIPZONE_INPUT// PR1_PRU1_PRU_R30_2/PR1_PRU1_PRU_R31_2/GPIO2_8
96 | LCD_DATA4 | T1 | | LCD_DATA4/GPMC_A4//EQEP2A_IN//PR1_PRU1_PRU_R30_4/ PR1_PRU1_PRU_R31_4/GPIO2_10
97 | LCD_DATA6 | T3 | | LCD_DATA6/GPMC_A6/PR1_EDIO_DATA_IN6/EQEP2_INDEX/ PR1_EDIO_DATA_OUT6/PR1_PRU1_PRU_R30_6/PR1_PRU1_PRU_R31_6/ GPIO2_12
98 | LCD_DATA8 | U1 | | LCD_DATA8/GPMC_A12/EHRPWM1_TRIPZONE_INPUT/ MCASP0_ACLKX/UART5_TXD/PR1_MII0_RXD3/UART2_CTSN/GPIO2_14
99 | LCD_DATA10 | U3 | | LCD_DATA10/GPMC_A14/EHRPWM1A/MCASP0_AXR0// PR1_MII0_RXD1/UART3_CTSN/GPIO2_16
100 | LCD_DATA12 | V2 | | LCD_DATA12/GPMC_A16/EQEP1A_IN/MCASP0_ACLKR/ MCASP0_AXR2/PR1_MII0_RXLINK/UART4_CTSN/GPIO0_8
101 | LCD_DATA14 | V4 | | LCD_DATA14/GPMC_A18/EQEP1_INDEX/MCASP0_AXR1/UART5_RXD/ PR1_MII_MR0_CLK/UART5_CTSN/GPIO0_10

102 DGND
103 | SPI1_SCLK | A13 | | MCASP0_ACLKX/EHRPWM0A//SPI1_SCLK/MMC0_SDCD/ PR1_PRU0_PRU_R30_0/PR1_PRU0_PRU_R31_0/GPIO3_14
104 | SPI1_D0 | B13 | | MCASP0_FSX/EHRPWM0B//SPI1_D0/MMC1_SDCD/ PR1_PRU0_PRU_R30_1/PR1_PRU0_PRU_R31_1/GPIO3_15
105 | SPI1_D1 | D12 | | MCASP0_AXR0/EHRPWM0_TRIPZONE_INPUT//SPI1_D1/MMC2_SDCD/ PR1_PRU0_PRU_R30_2/PR1_PRU0_PRU_R31_2/GPIO3_16

# BCMMODULE BCM1

11

Pin on BGA | Transfer-Signal on BGA | from Pin AM3358BZCZ100 | from Pin TPS65217CRSLR | comment
106 | SPI1_CS0 | C12 | | MCASP0_AHCLKR/EHRPWM0_SYNCI_O/MCASP0_AXR2/SPI1_CS0/ ECAP2_IN_PWM2_OUT/PR1_PRU0_PRU_R30_3/ PR1_PRU0_PRU_R31_3/GPIO3_17
107 | USB1_DRVVBUS | F15 | | USB1_DRVVBUS/GPIO3_13
108 | USB1_CE | P18
109 | USB1_VBUS | T18
110 DGND
111 | LCD_DATA1 | R2 | | LCD_DATA1/GPMC_A1//EHRPWM2B//PR1_PRU1_PRU_R30_1/ PR1_PRU1_PRU_R31_1/GPIO2_7
112 | LCD_DATA3 | R4 | | LCD_DATA3/GPMC_A3//EHRPWM2_SYNCI_O//PR1_PRU1_PRU_R30_3/ PR1_PRU1_PRU_R31_3/GPIO2_9
113 | LCD_DATA5 | T2 | | LCD_DATA5/GPMC_A5//EQEP2B_IN//PR1_PRU1_PRU_R30_5/ PR1_PRU1_PRU_R31_5/GPIO2_11
114 | LCD_DATA7 | T4 | | LCD_DATA7/GPMC_A7/PR1_EDIO_DATA_IN7/EQEP2_STROBE/ PR1_EDIO_DATA_OUT7/PR1_PRU1_PRU_R30_7/PR1_PRU1_PRU_R31_7/ GPIO2_13
115 | LCD_DATA9 | U2 | | LCD_DATA9/GPMC_A13/EHRPWM1_SYNCI_O/MCASP0_FSX/UART5_RXD/ PR1_MII0_RXD2/UART2_RTSN/GPIO2_15
116 | LCD_DATA11 | U4 | | LCD_DATA11/GPMC_A15/EHRPWM1B/MCASP0_AHCLKR/MCASP0_AXR2/ PR1_MII0_RXD0/UART3_RTSN/GPIO2_17
117 | LCD_DATA13 | V3 | | LCD_DATA13/GPMC_A17/EQEP1B_IN/MCASP0_FSR/MCASP0_AXR3/ PR1_MII0_RXER/UART4_RTSN/GPIO0_9
118 | LCD_DATA15 | T5 | | LCD_DATA15/GPMC_A19/EQEP1_STROBE/MCASP0_AHCLKX/ MCASP0_AXR3/PR1_MII0_RXDV/UART5_RTSN/GPIO0_11

119 DGND
120 | LCDDE | R6 | LCD_AC_BIAS_EN/GPMC_A11//PR1_EDIO_DATA_IN5/ PR1_EDIO_DATA_OUT5/PR1_PRU1_PRU_R30_11/ PR1_PRU1_PRU_R31_11/GPIO2_25

121 DGND
122 | eMMC_RSTn | R14 (über Inverter IC3) | GPMC_A4/GMII2_TXD1/RGMII2_TD1/RMII2_TXD1/GPMC_A20/ PR1_MII1_TXD0/EQEP1A_IN/GPIO1_20
123 | MMC1_DAT0 | U7 | GPMC_AD0/MMC1_DAT0//////GPIO1_0
124 | MMC1_DAT1 | V7 | GPMC_AD1/MMC1_DAT1//////GPIO1_1
125 | MMC1_DAT2 | R8 | GPMC_AD2/MMC1_DAT2//////GPIO1_2

# BCMMODULE BCM1

12

Pin on BGA | Transfer-Signal on BGA | from Pin AM3358BZCZ100 | from Pin TPS65217CRSLR | comment
126 | MMC1_DAT3 | T8 | | GPMC_AD3/MMC1_DAT3//////GPIO1_3
127 | MMC1_DAT4 | U8 | | GPMC_AD4/MMC1_DAT4//////GPIO1_4
128 | MMC1_DAT5 | V8 | | GPMC_AD5/MMC1_DAT5//////GPIO1_5
129 | MMC1_DAT6 | R9 | | GPMC_AD6/MMC1_DAT6//////GPIO1_6
130 | MMC1_DAT7 | T9 | | GPMC_AD7/MMC1_DAT7//////GPIO1_7
131 | MMC1_CLK | U9 | | GPMC_CSN1/GPMC_CLK/MMC1_CLK/PRT1EDIO_DATA_IN6/ PRT1_EDIO_DATA_OUT6/PR1_PRU1_PRU_R30_12/ PR1_PRU1_PRU_R31_12/GPIO1_30

132 DGND
133 | GPIO0_26 | T11 | | GPMC_AD10/LCD_DATA21/MMC1_DAT2/MMC2_DAT6/ EHRPWM2_TRIPZONE_INPUT/PR1_MII0_TXEN//GPIO0_26
134 | GPIO0_27 | U12 | | GPMC_AD11/LCD_DATA20/MMC1_DAT3/MMC2_DAT7/ EHRPWM2_SYNCI_O/PR1_MII0_TXD3//GPIO0_27
135 | HDMI_INT | U16 | | GPMC_A9/GMII2_RXD2/RGMII2_RD2/MMC2_DAT7/GPMC_A25/ PR1_MII_MR1_CLK/MCASP0_FSX/GPIO1_25
136 | HDMICLK_DISn | V17 | | GPMC_A11/GMII2_RXD0/RGMII2_RD0/RMII2_RXD0/GPMC_A27/ PR1_MII1_RXER/MCASP0_AXR1/GPIO1_27
137 | GPIO1_13 | R12 | | GPMC_AD13/LCD_DATA18/MMC1_DAT5/MMC2_DAT1/EQEP2B_IN/ PR1_MII0_TXD1/PR1_PRU0_PRU_R30_15/GPIO1_13
138 | GPIO1_15 | U13 | | GPMC_AD15/LCD_DATA16/MMC1_DAT7/MMC2_DAT3/EQEP2_STROBE/ PR1_ECAP0_ECAP_CAPIN_APWM_O/PR1_PRU0_PRU_R31_15/GPIO1_15
139 | GPIO1_16 | R13 | | GPMC_A0/GMII2_TXEN/RGMII2_TCTL/RMII2_TXEN/GPMC_A16/ PR1_MII_MT1_CLK/EHRPWM1_TRIPZONE_INPUT/GPIO1_16
140 | USR1 | U15 | | GPMC_A6/GMII2_TXCLK/RGMII2_TCLK/MMC2_DAT4/GPMC_A22/ PR1_MII1_RXD2/EQEP1_INDEX/GPIO1_22
141 | USR3 | V16 | | GPMC_A8/GMII2_RXD3/RGMII2_RD3/MMC2_DAT6/GPMC_A24/ PR1_MII1_RXD0/MCASP0_ACLKX/GPIO1_24
142 | USB0_VBUS | P15
143 | USB0_CE | M15
144 | LCDPCLK | V5 | | LCD_PCLK/GPMC_A10//PR1_EDIO_DATA_IN4/PR1_EDIO_DATA_OUT4/ PR1_PRU1_PRU_R30_10/PR1_PRU1_PRU_R31_10/GPIO2_24
145 | LCDHSYNC | R5 | | LCD_HSYNC/GPMC_A9//PR1_EDIO_DATA_IN3/PR1_EDIO_DATA_OUT3/ PR1_PRU1_PRU_R30_9/PR1_PRU1_PRU_R31_9/GPIO2_23
146 | LCDVSYNC | U5 | | LCD_VSYNC/GPMC_A8//PR1_EDIO_DATA_IN2/PR1_EDIO_DATA_OUT2/ PR1_PRU1_PRU_R30_8/PR1_PRU1_PRU_R31_8/GPIO2_22

# BCMMODULE BCM1

13

Pin on BGA | Transfer-Signal on BGA | from Pin AM3358BZCZ100 | from Pin TPS65217CRSLR | comment

147 DGND
148 | TIMER4 | R7 | | GPMC_ADVN_ALE/TIMER4/GPIO2_2
149 | TIMER5 | T6 | | GPMC_BE0N_CLE/TIMER5/GPIO2_5
150 | TIMER6 | U6 | | GPMC_WEN/TIMER6/GPIO2_4
151 | TIMER7 | T7 | | GPMC_OEN_REN/TIMER7/EMU4/GPIO2_3
152 DGND
153 | GPIO1_29 | V6 | | GPMC_CSN0/GPIO1_29
154 | EHRPWM2A | U10 | | GPMC_AD8/LCD_DATA23/MMC1_DAT0/MMC2_DAT4/EHRPWM2A/ PR1_MII_MT0_CLK//GPIO0_22
155 | EHRPWM2B | T10 | | GPMC_AD9/LCD_DATA22/MMC1_DAT1/MMC2_DAT5/EHRPWM2B/ PR1_MII0_CRS//GPIO0_23
156 | MMC1_CMD | V9 | | GPMC_CSN2/GPMC_BE1N/MMC1_CMD/PR1_EDIO_DATA_IN7/ PR1_EDIO_DATA_OUT7/PR1_PRU1_PRU_R30_13/ PR1_PRU1_PRU_R31_13/GPIO1_31

157 DGND
158 | GPIO2_1 | V12 | | GPMC_CLK/LCD_MEM_CLK/GPMC_WAIT1/MMC2_CLK/ PRT1_MII1_TXEN/MCASP0_FSR/GPIO2_1
159 | GPIO2_0 | T13 | | GPMC_CSN3/MMC2_CMD/PR1_MDIO_DATA/GPIO2_0
160 | GPIO1_17 | V14 | | GPMC_A1/GMII2_RXDV/RGMII2_RCTL/MMC2_DAT0/GPMC_A17/ PR1_MII1_TXD3/EHRPWM1_SYNCI_O/GPIO1_17

161 DGND
162 | GPIO1_12 | T12 | | GPMC_AD12/LCD_DATA19/MMC1_DAT4/MMC2_DAT0/EQEP2A_IN/ PR1_MII0_TXD2/PR1_PRU0_PRU_R30_14/GPIO1_12
163 | GPIO1_14 | V13 | | GPMC_AD14/LCD_DATA17/MMC1_DAT6/MMC2_DAT2/EQEP2_INDEX/ PR1_MII0_TXD0/PR1_PRU0_PRU_R31_14/GPIO1_14
164 | USR0 | V15 | | GPMC_A5/GMII2_TXD0/RGMII2_TD0/RMII2_TXD0/GPMC_A21/ PR1_MII1_RXD3/EQEP1B_IN/GPIO1_21
165 | USR2 | T15 | | GPMC_A7/GMII2_RXCLK/RGMII2_RCLK/MMC2_DAT5/GPMC_A23/ PR1_MII1_RXD1/EQEP1_STROBE/GPIO1_23

166 DGND
167 | USB0_ID | P16
168 | USB0_DRVVBUS | F16 | | Reserved for future use

# BCMMODULE BCM1

14

Pin on BGA | Transfer-Signal on BGA | from Pin AM3358BZCZ100 | from Pin TPS65217CRSLR | comment
A2 | DGND
A3 | VDD_CORE
A4 | VDD_5V
A5 | VDD_5V
B1 | VDD_3V3B
B2 | DGND
B3 | VDD_MPU
B4 | SYS_5V
B5 | VDD_USB_DC
C1 | VDD_3V3B
C2 | VDD_PLL
C3 | VDD_1V8
C4 | VDD_1V8
C5 | VDD_S
G1 | VDD_3V3A
G2 | DGND
G3 | VDD_S
G4 | DGND
G5 | DGNDA_ADC
H1 | VDD_CORE
H2 | DGND
H3 | DGND
H4 | DGND
H5 | VDD_ADC
I1 | VDD_CORE
I2 | DGND
I3 | VDDS_DDR
I4 | DGND
I5 | VDDS_DDR

# BCMMODULE BCM1

15

# 3.3 Color-Legend for Signal-Type

MII
USB
BKL
UART
JTAG
MMC
JTAG
AIN
LCD
eMMC
Reserved for future use

# 4. Change History

The following table reflects the changes made to BCM1.

Revision | Comments | Date | Editor
1.0 | Original release | 2016-03-07 | ANS
1.1 | Correction Signals Pin 71 and 72 and footprint drawing | 2016-07-19 | FIN
1.2 | Correction in Pin Signals Table (B4: SYS_5V) | 2017-11-30 | ANS
1.3 Correction in Pin Signals Table (19, 20, 32, 33, 55, | 62, 71, 72, 81, 109, 122, 142) | 2019-07-31 | MIE

# 5. Open Hardware

BCMmodule is built upon the Open Hardware Schematics of BeagleBone Black which has been created and published by the BeagleBoard.org Foundation. Just like the BeagleBone Black the BCMmodule BCM1 is published under Creative Commons (CC-BY-SA 3.0).

# BCMMODULE BCM1

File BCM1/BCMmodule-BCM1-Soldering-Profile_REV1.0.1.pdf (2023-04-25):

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

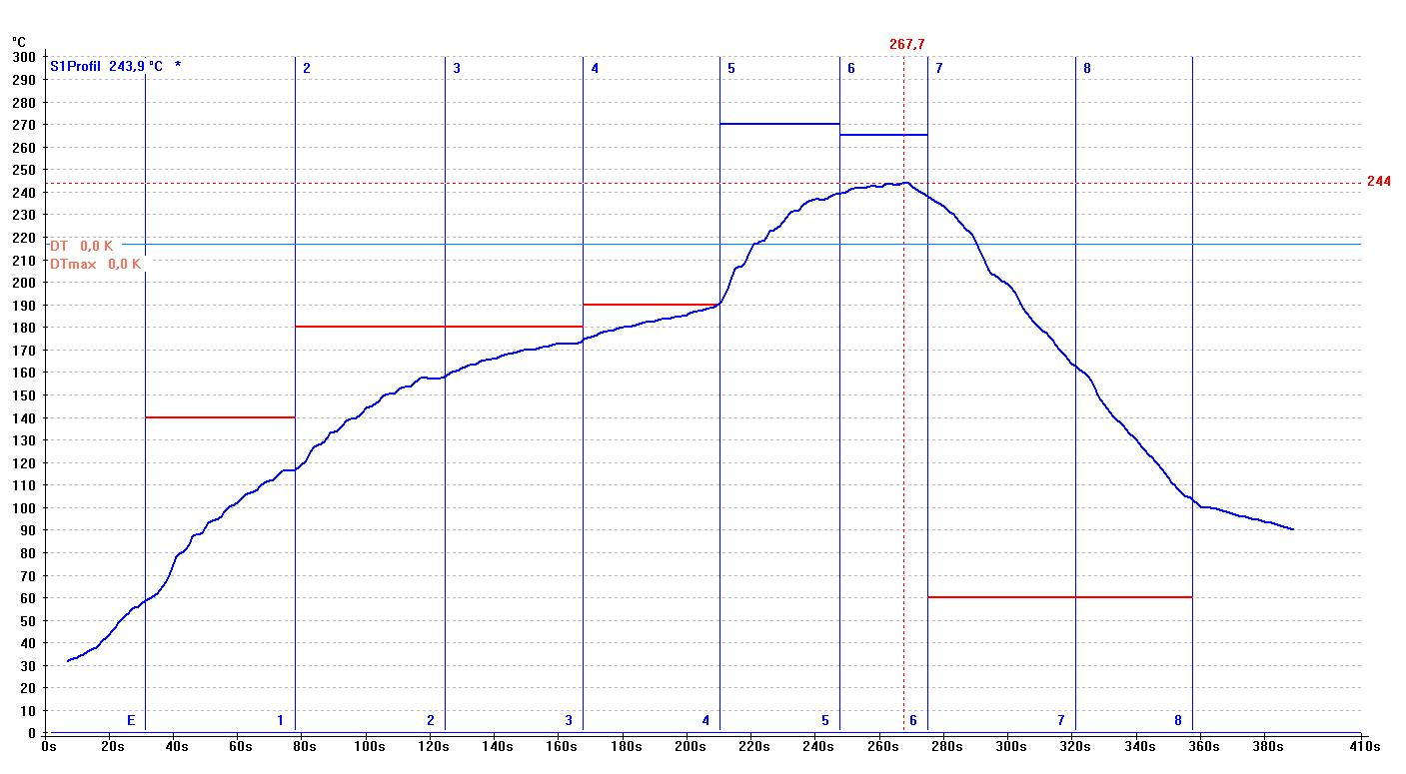
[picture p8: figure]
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

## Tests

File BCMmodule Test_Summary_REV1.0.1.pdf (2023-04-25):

1

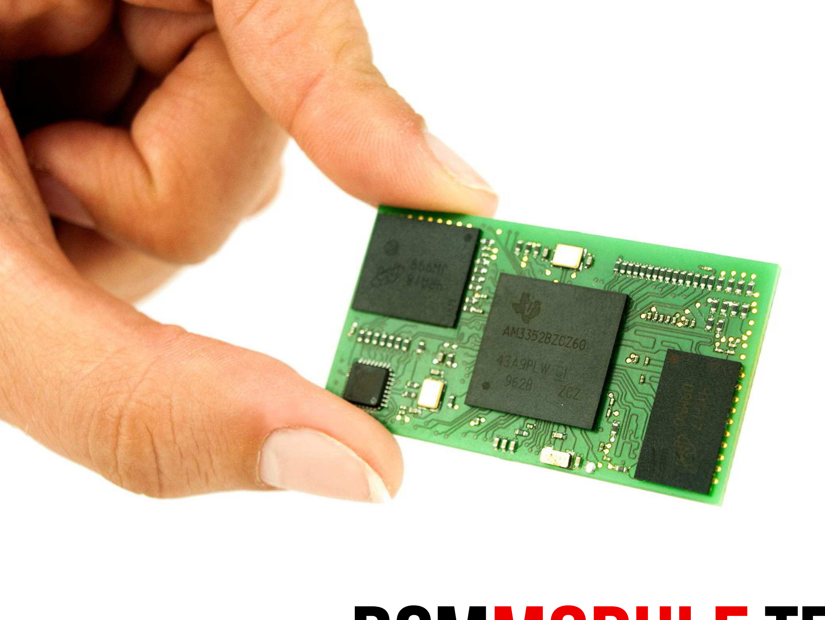
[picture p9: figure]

# BCMMODULEtest summary

### The following use cases are already tested

All tests were performed using minicom on a linux desktop pc connected to BCMmodule via FTDI cable. For the linux tests BCMmodule was booted using the latest BeagleBone Debian Image.
- Power supply device via DC plug
- Power supply device via USB host interface
- Power on/off device by power button
- Reset device by reset button
- Connect to rom boot loader via FTDI cable
- Download and install u-boot via FTDI cable
- Boot linux from microSD card
- Install linux to onboard flash memory
- Boot linux from onboard flash memory
- Boot linux from microSD card using the boot select button
- Access network via Ethernet interface
- Access USB memory sticks connected to USB device interface
- Access BCMmodule as USB memory via USB host interface
- Recognize different capes connected to the cape connector

2

- Display the linux desktop on a display connected to micro HDMI interface
- Use USB mouse and keyboard to operate the linux desktop
- Boot BBB Android 4.4.4 and use 4.3” LCD cape as display and touch device

### The following use cases are not yet tested

- Boot Linux from ethernet network
- Operation of various USB gadgets
- Operation of various BeagleBone Black capes

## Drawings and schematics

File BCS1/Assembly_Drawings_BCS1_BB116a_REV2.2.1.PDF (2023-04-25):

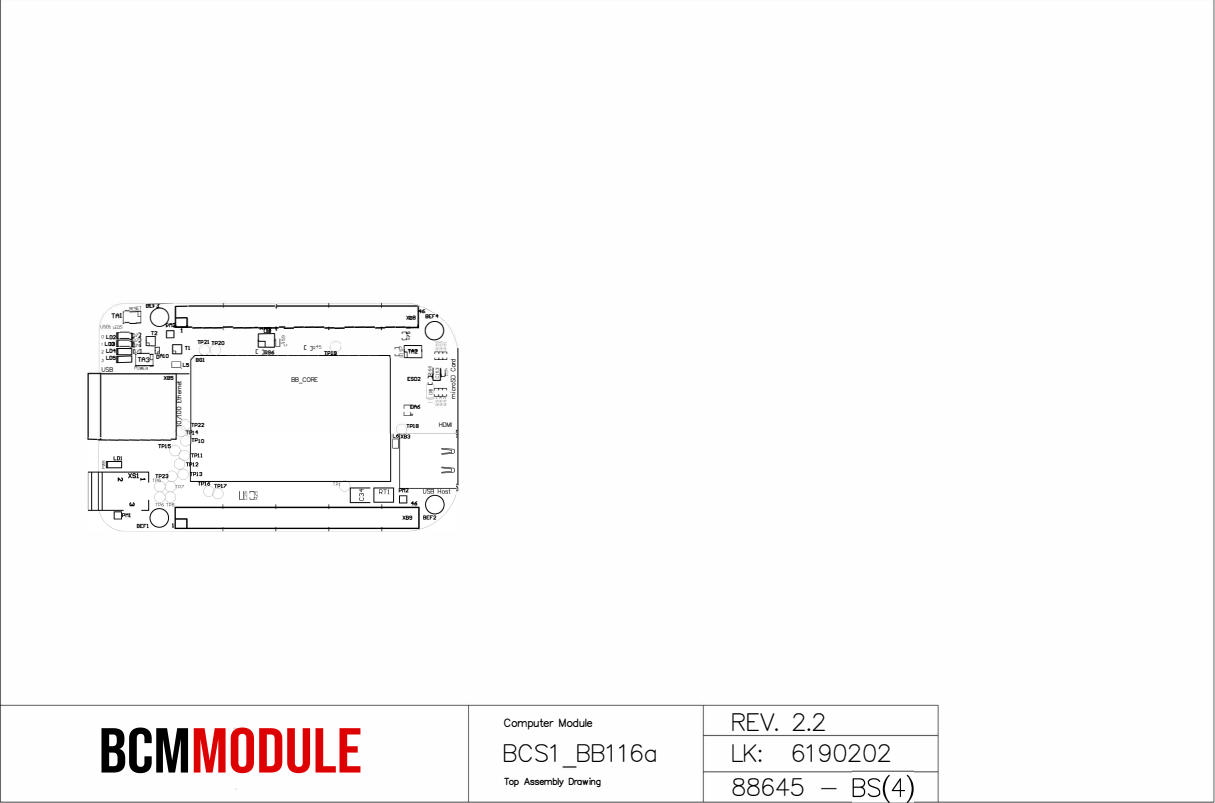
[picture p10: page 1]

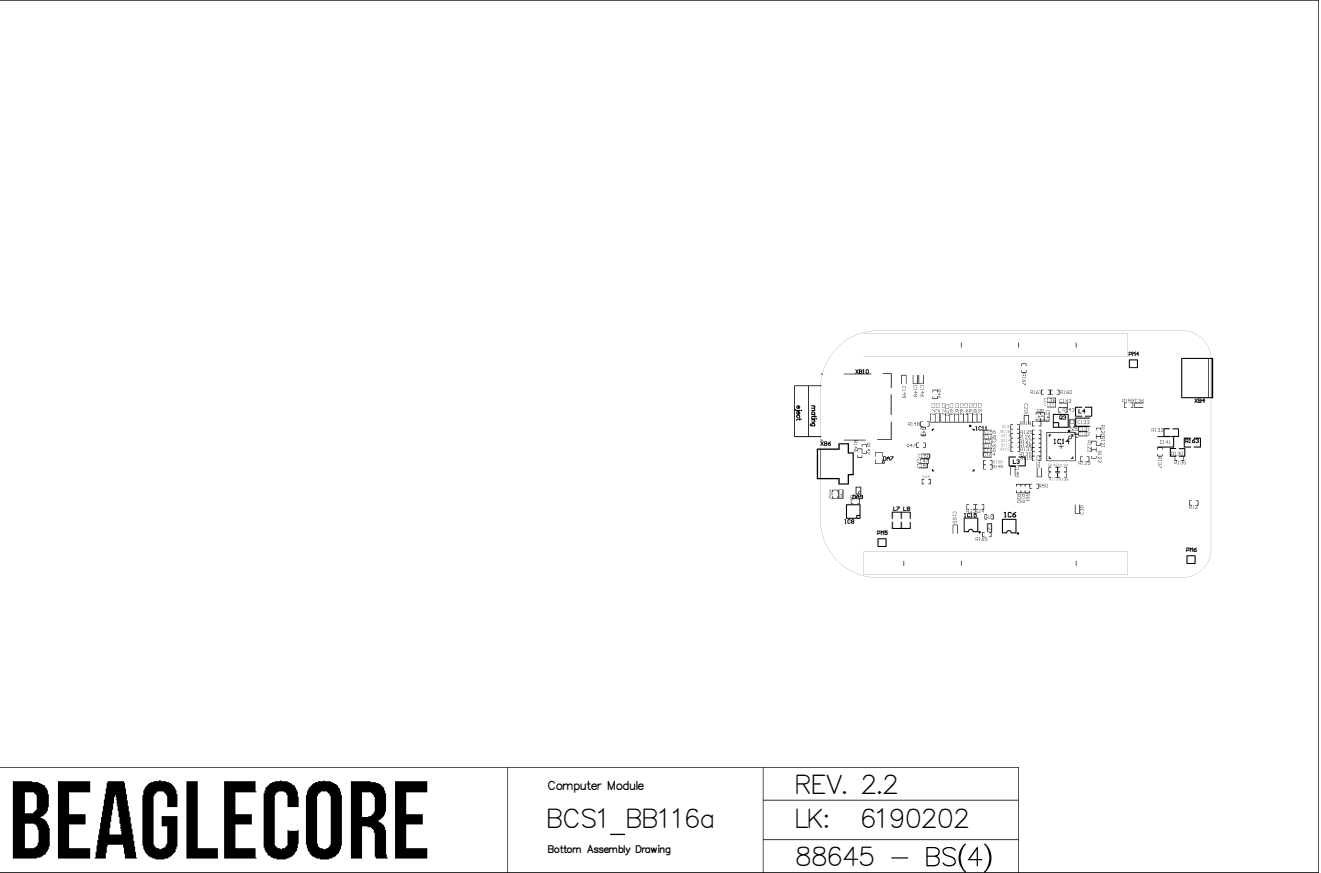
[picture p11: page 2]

Bottom Assembly Draw ing

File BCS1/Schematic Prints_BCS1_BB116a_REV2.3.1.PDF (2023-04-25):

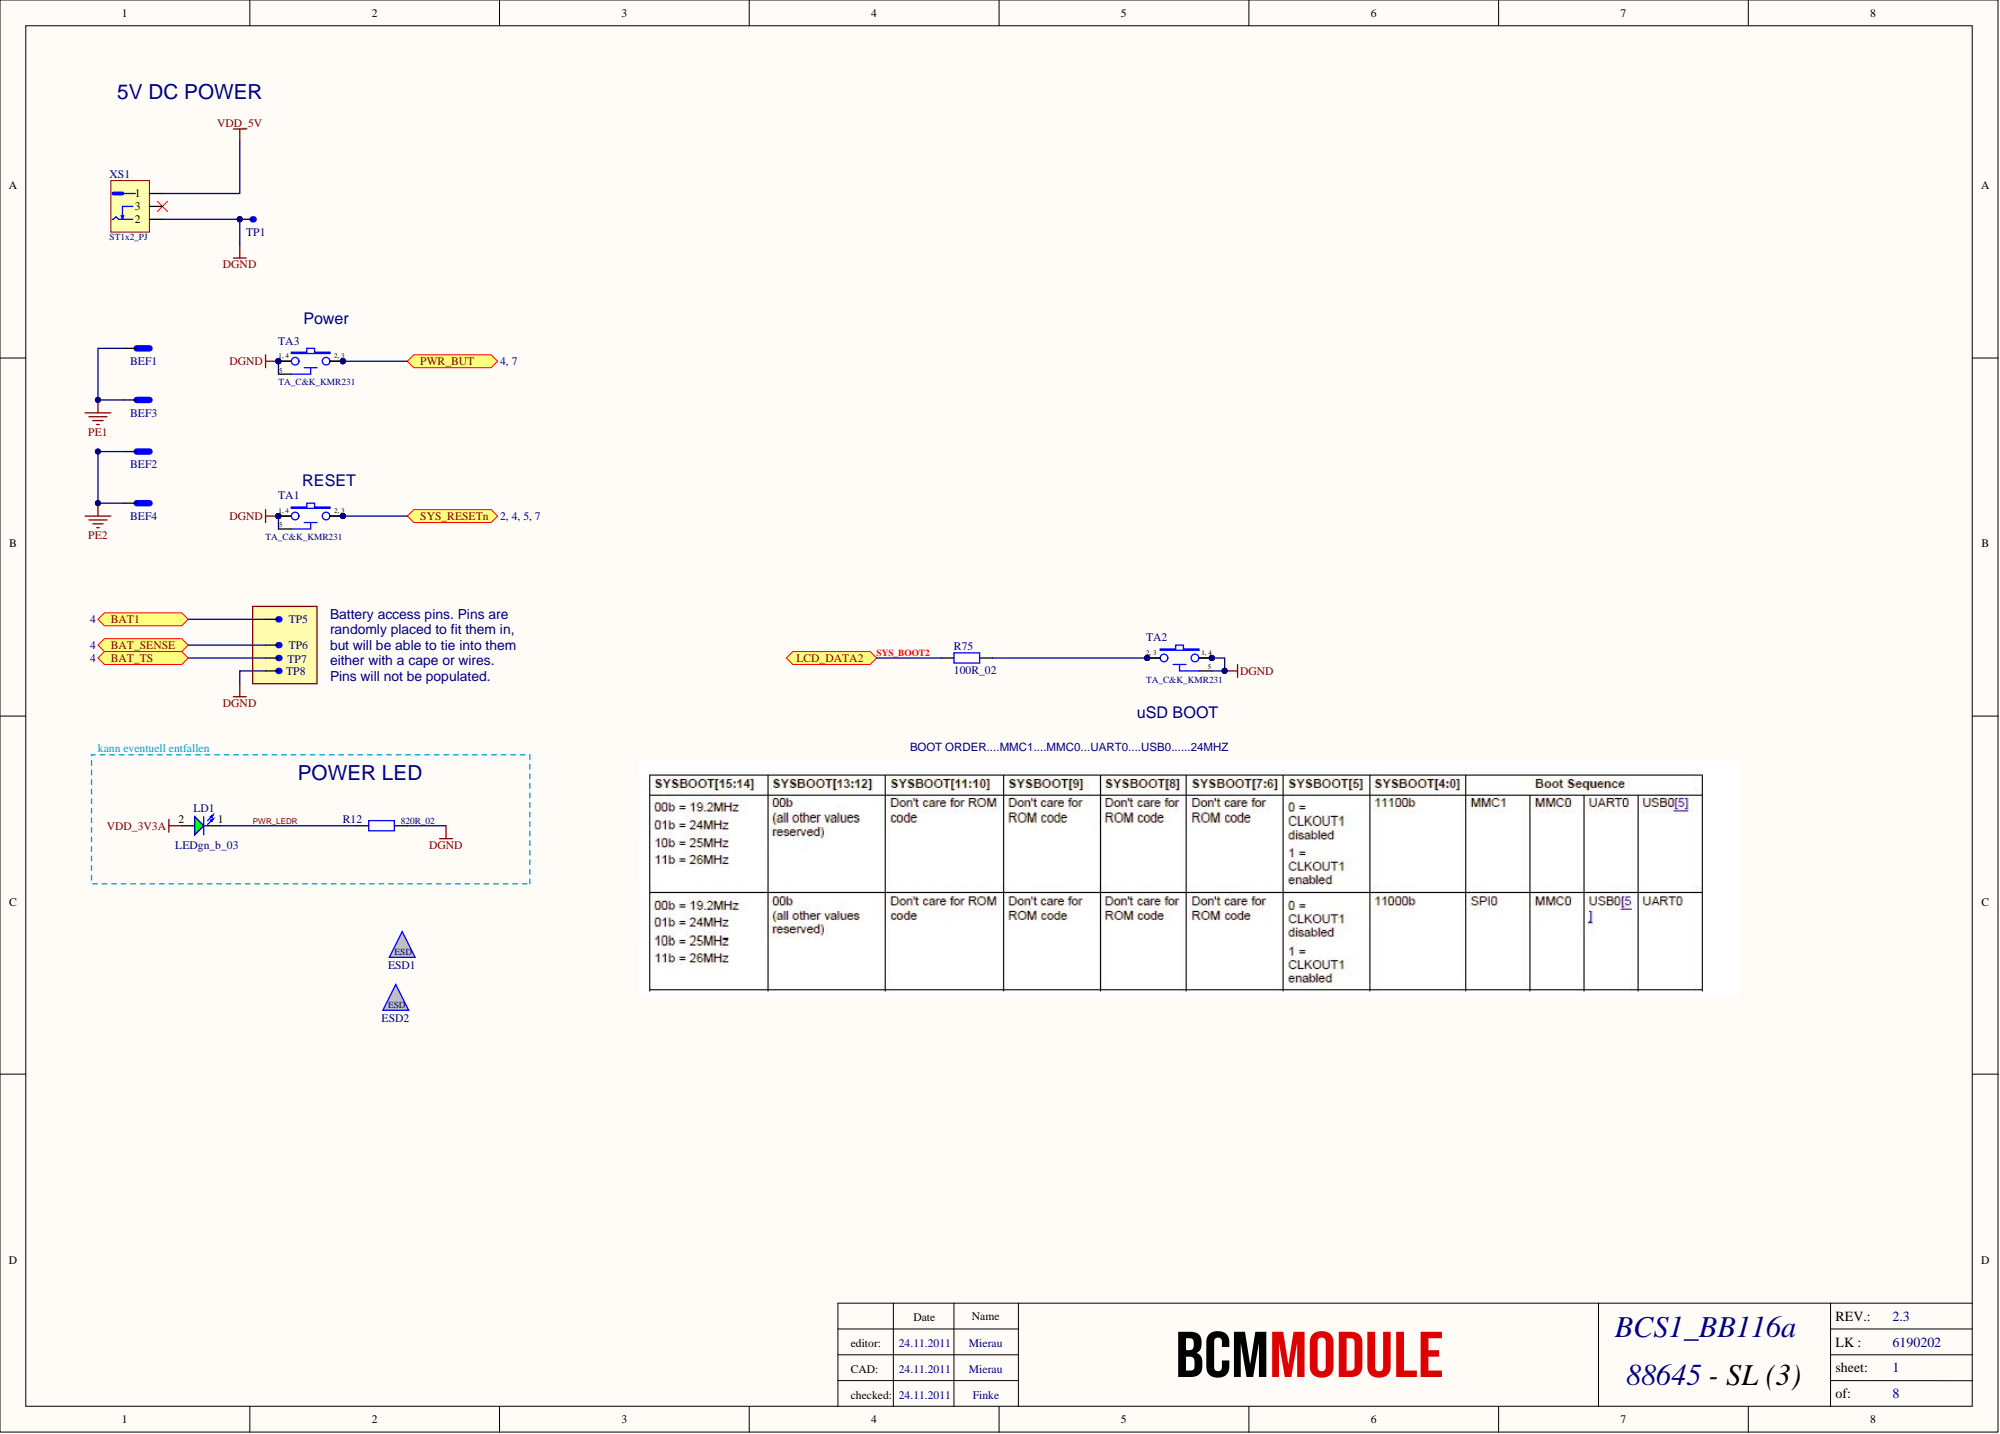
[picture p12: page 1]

Battery access pins. Pins are
randomly placed to fit them in,
but will be able to tie into them
either with a cape or wires.
Pins will not be populated.

editor: | Mierau

CAD: | Mierau

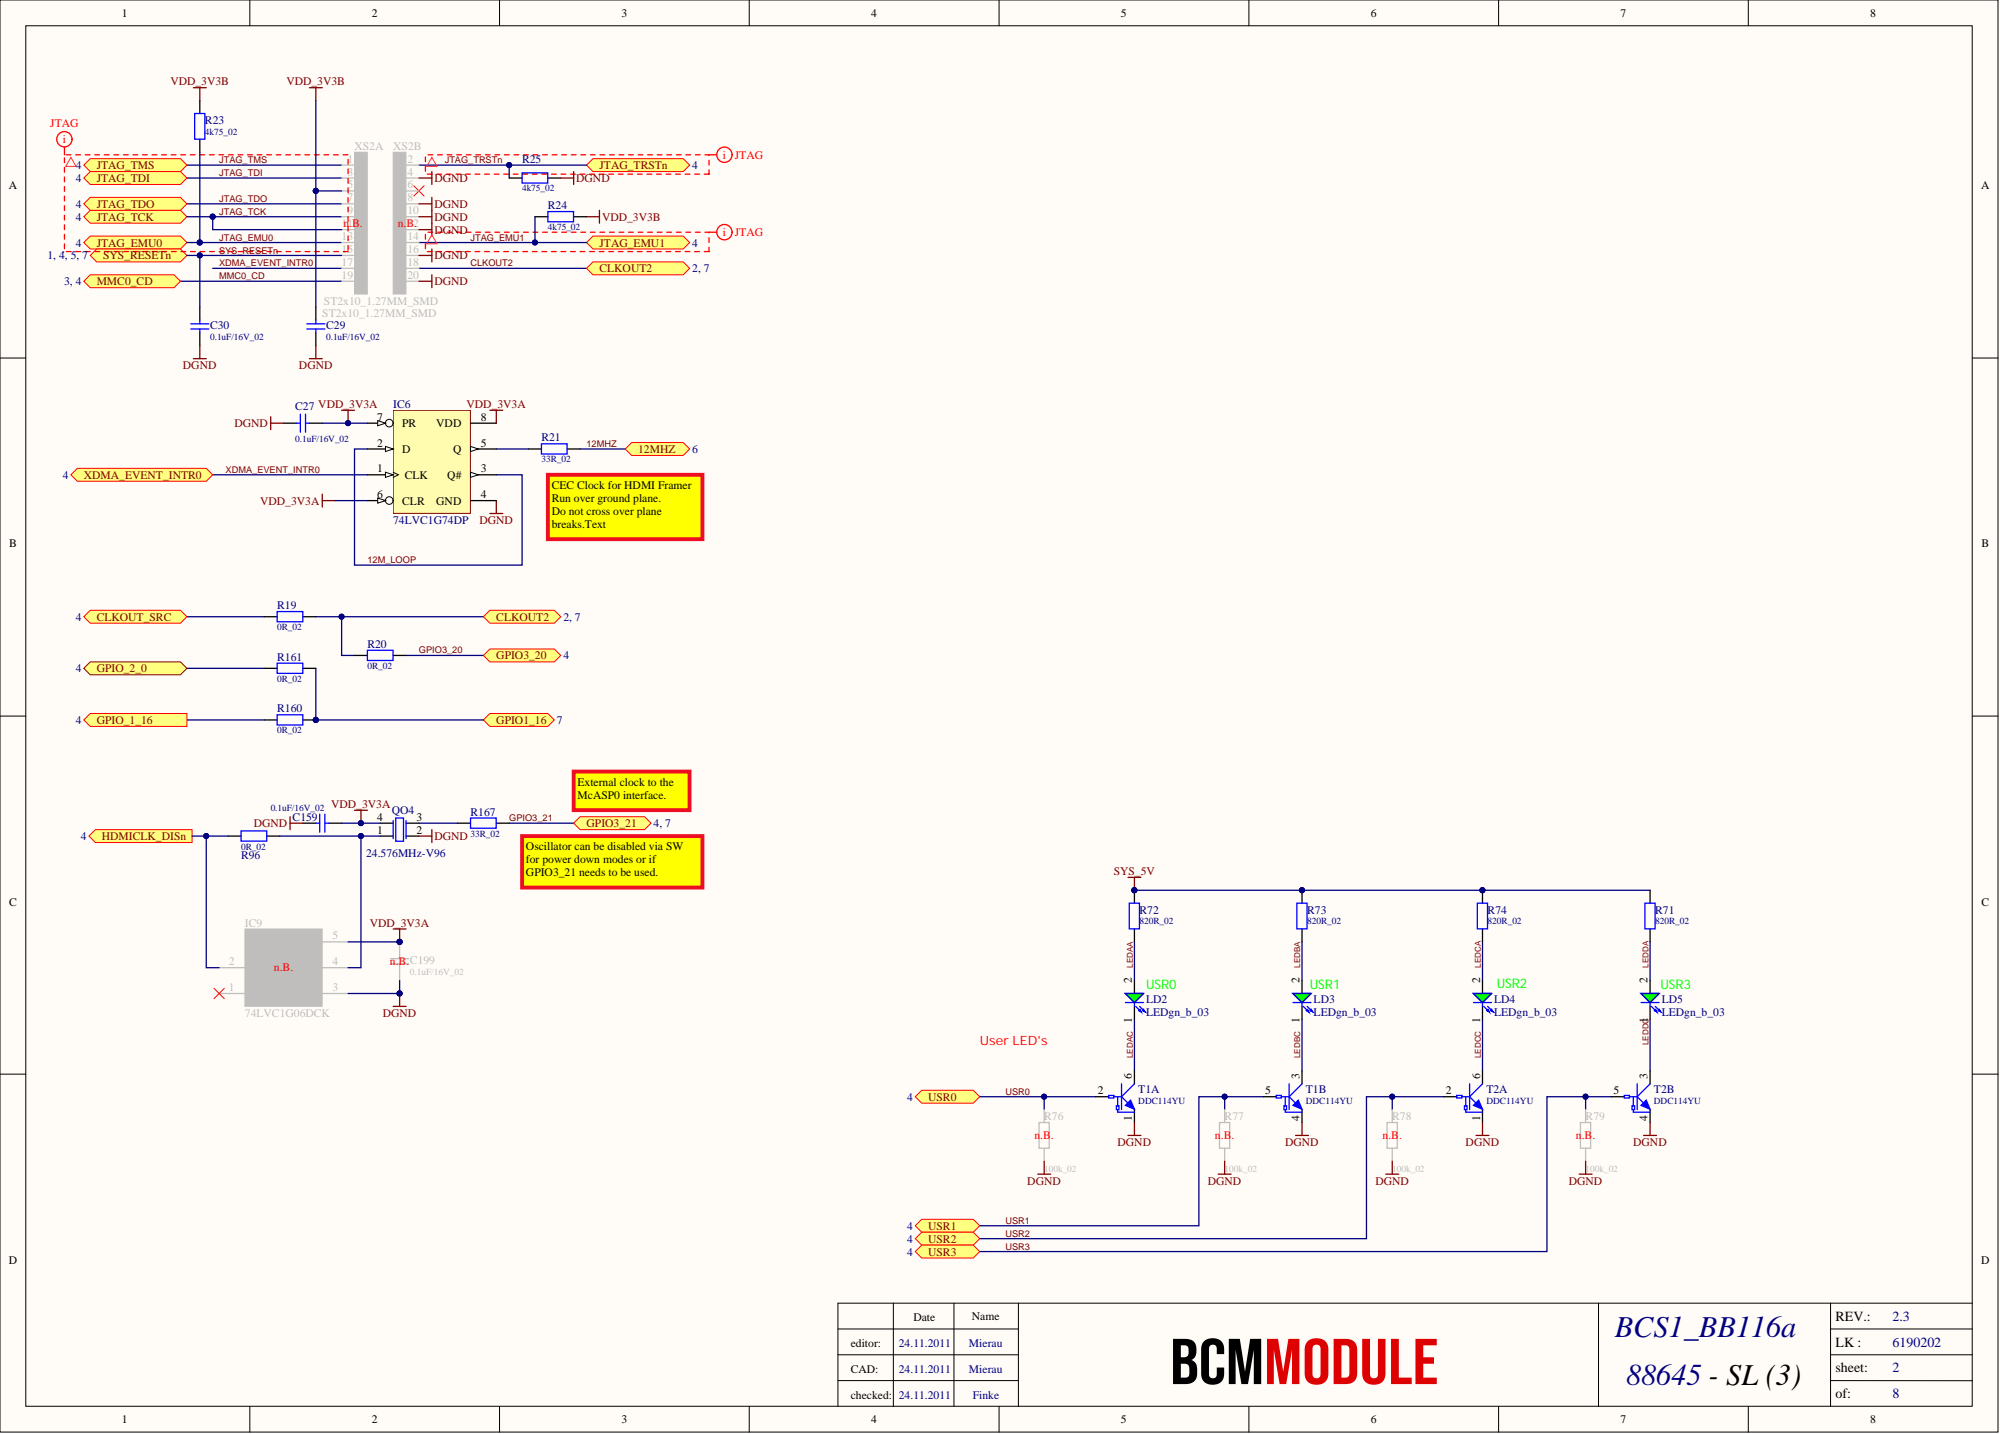
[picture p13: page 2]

CEC Clock for HDMI Framer
Run over ground plane.
Do not cross over plane
breaks.Text

External clock to the
McASP0 interface.

Oscillator can be disabled via SW
for power down modes or if
GPIO3_21 needs to be used.

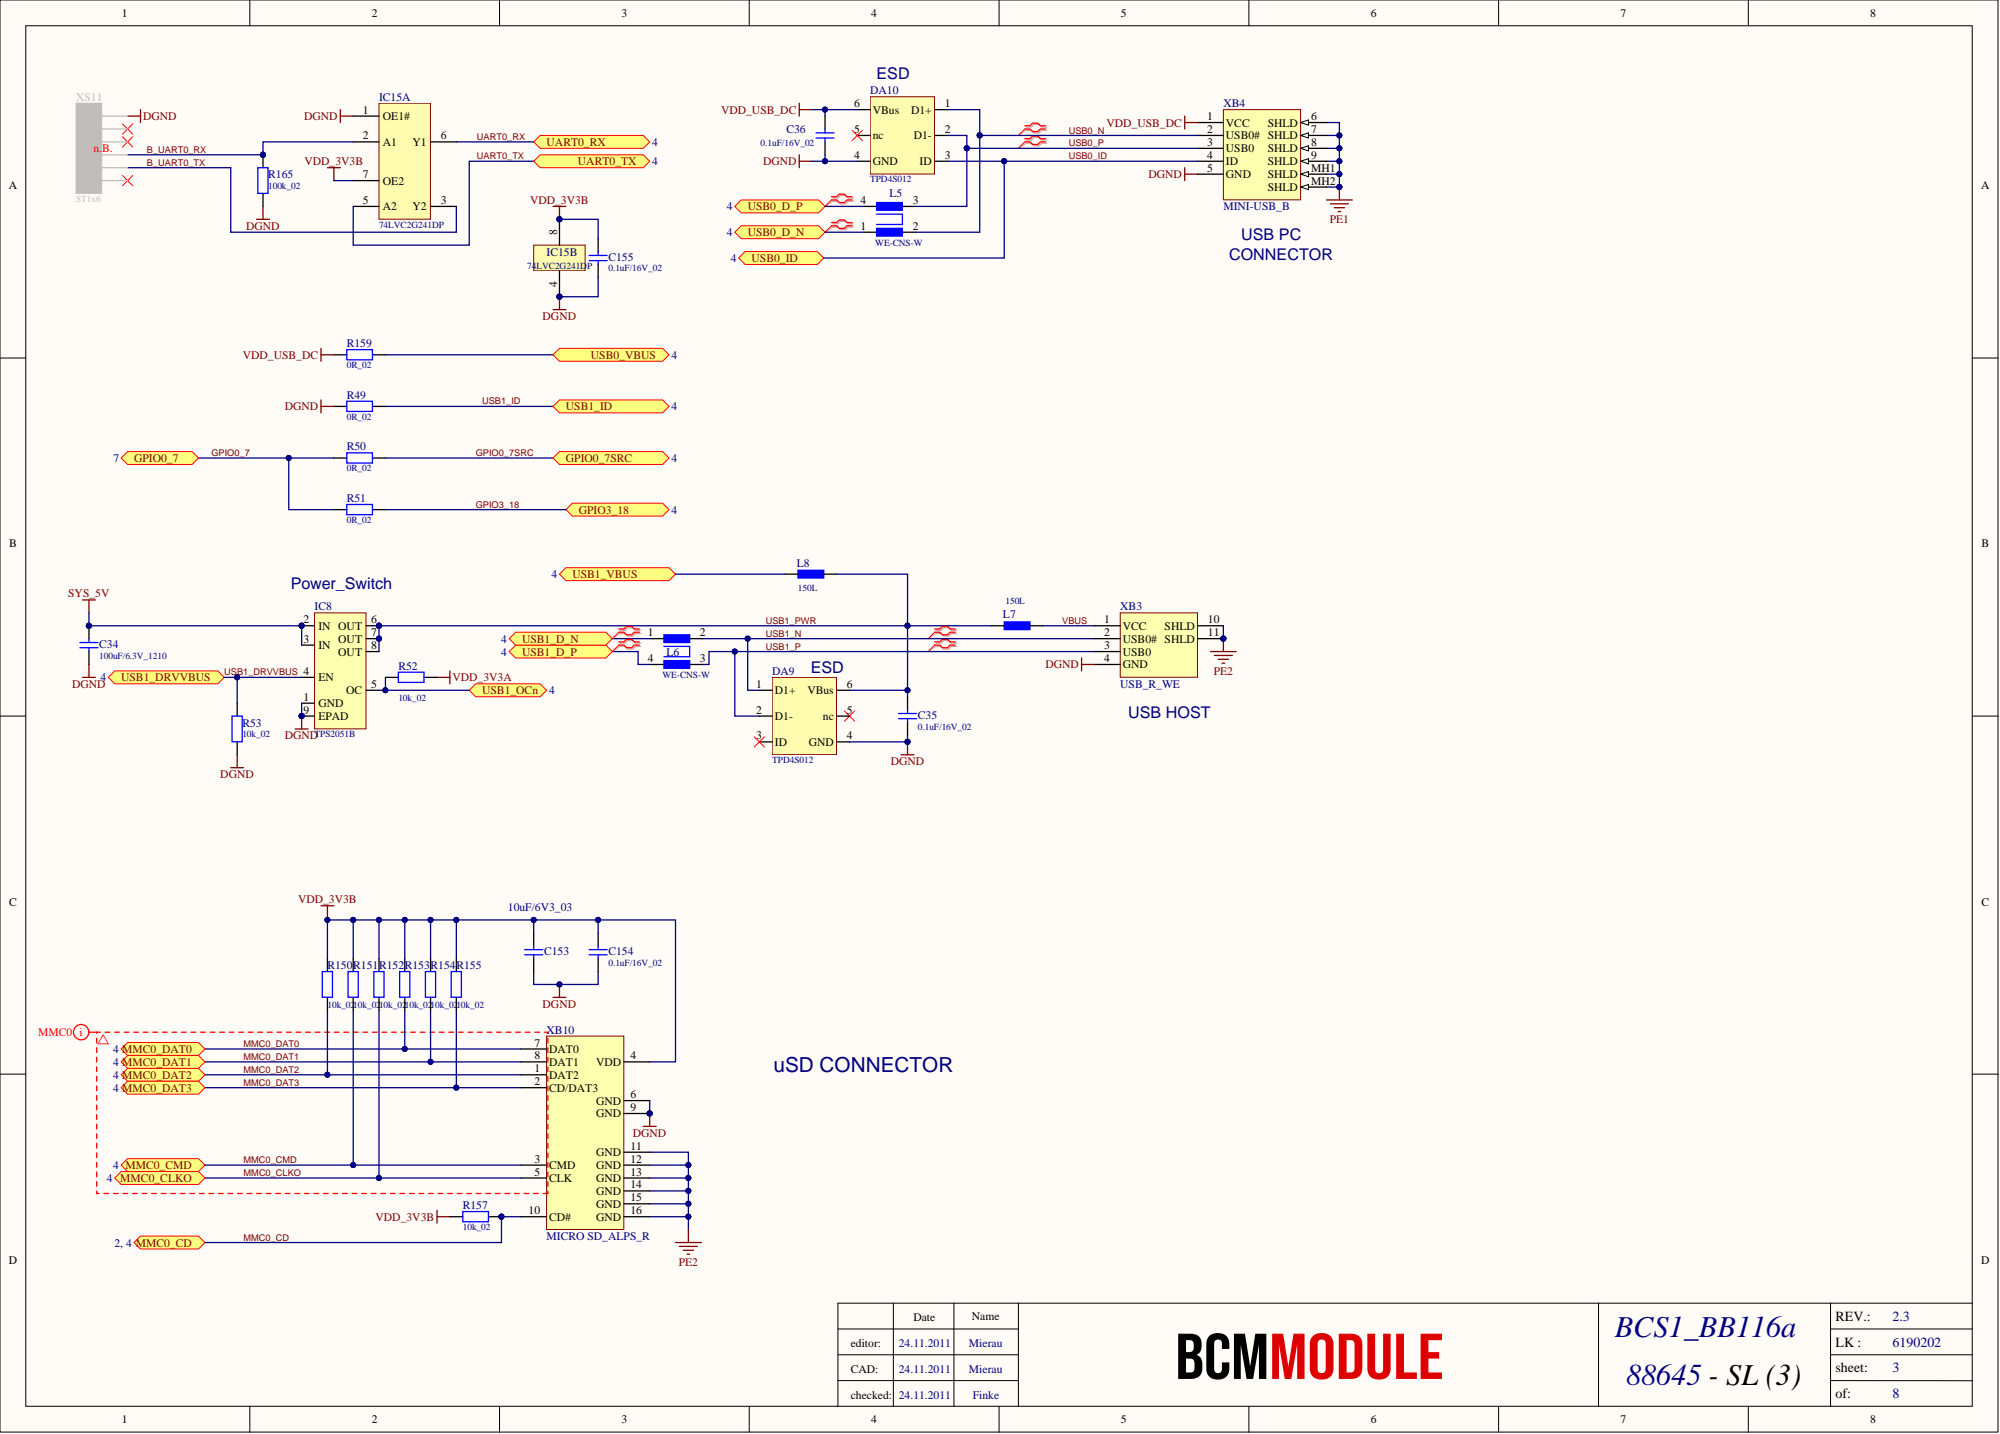
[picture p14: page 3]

USB1_P | | USB0 3
ESD DA9

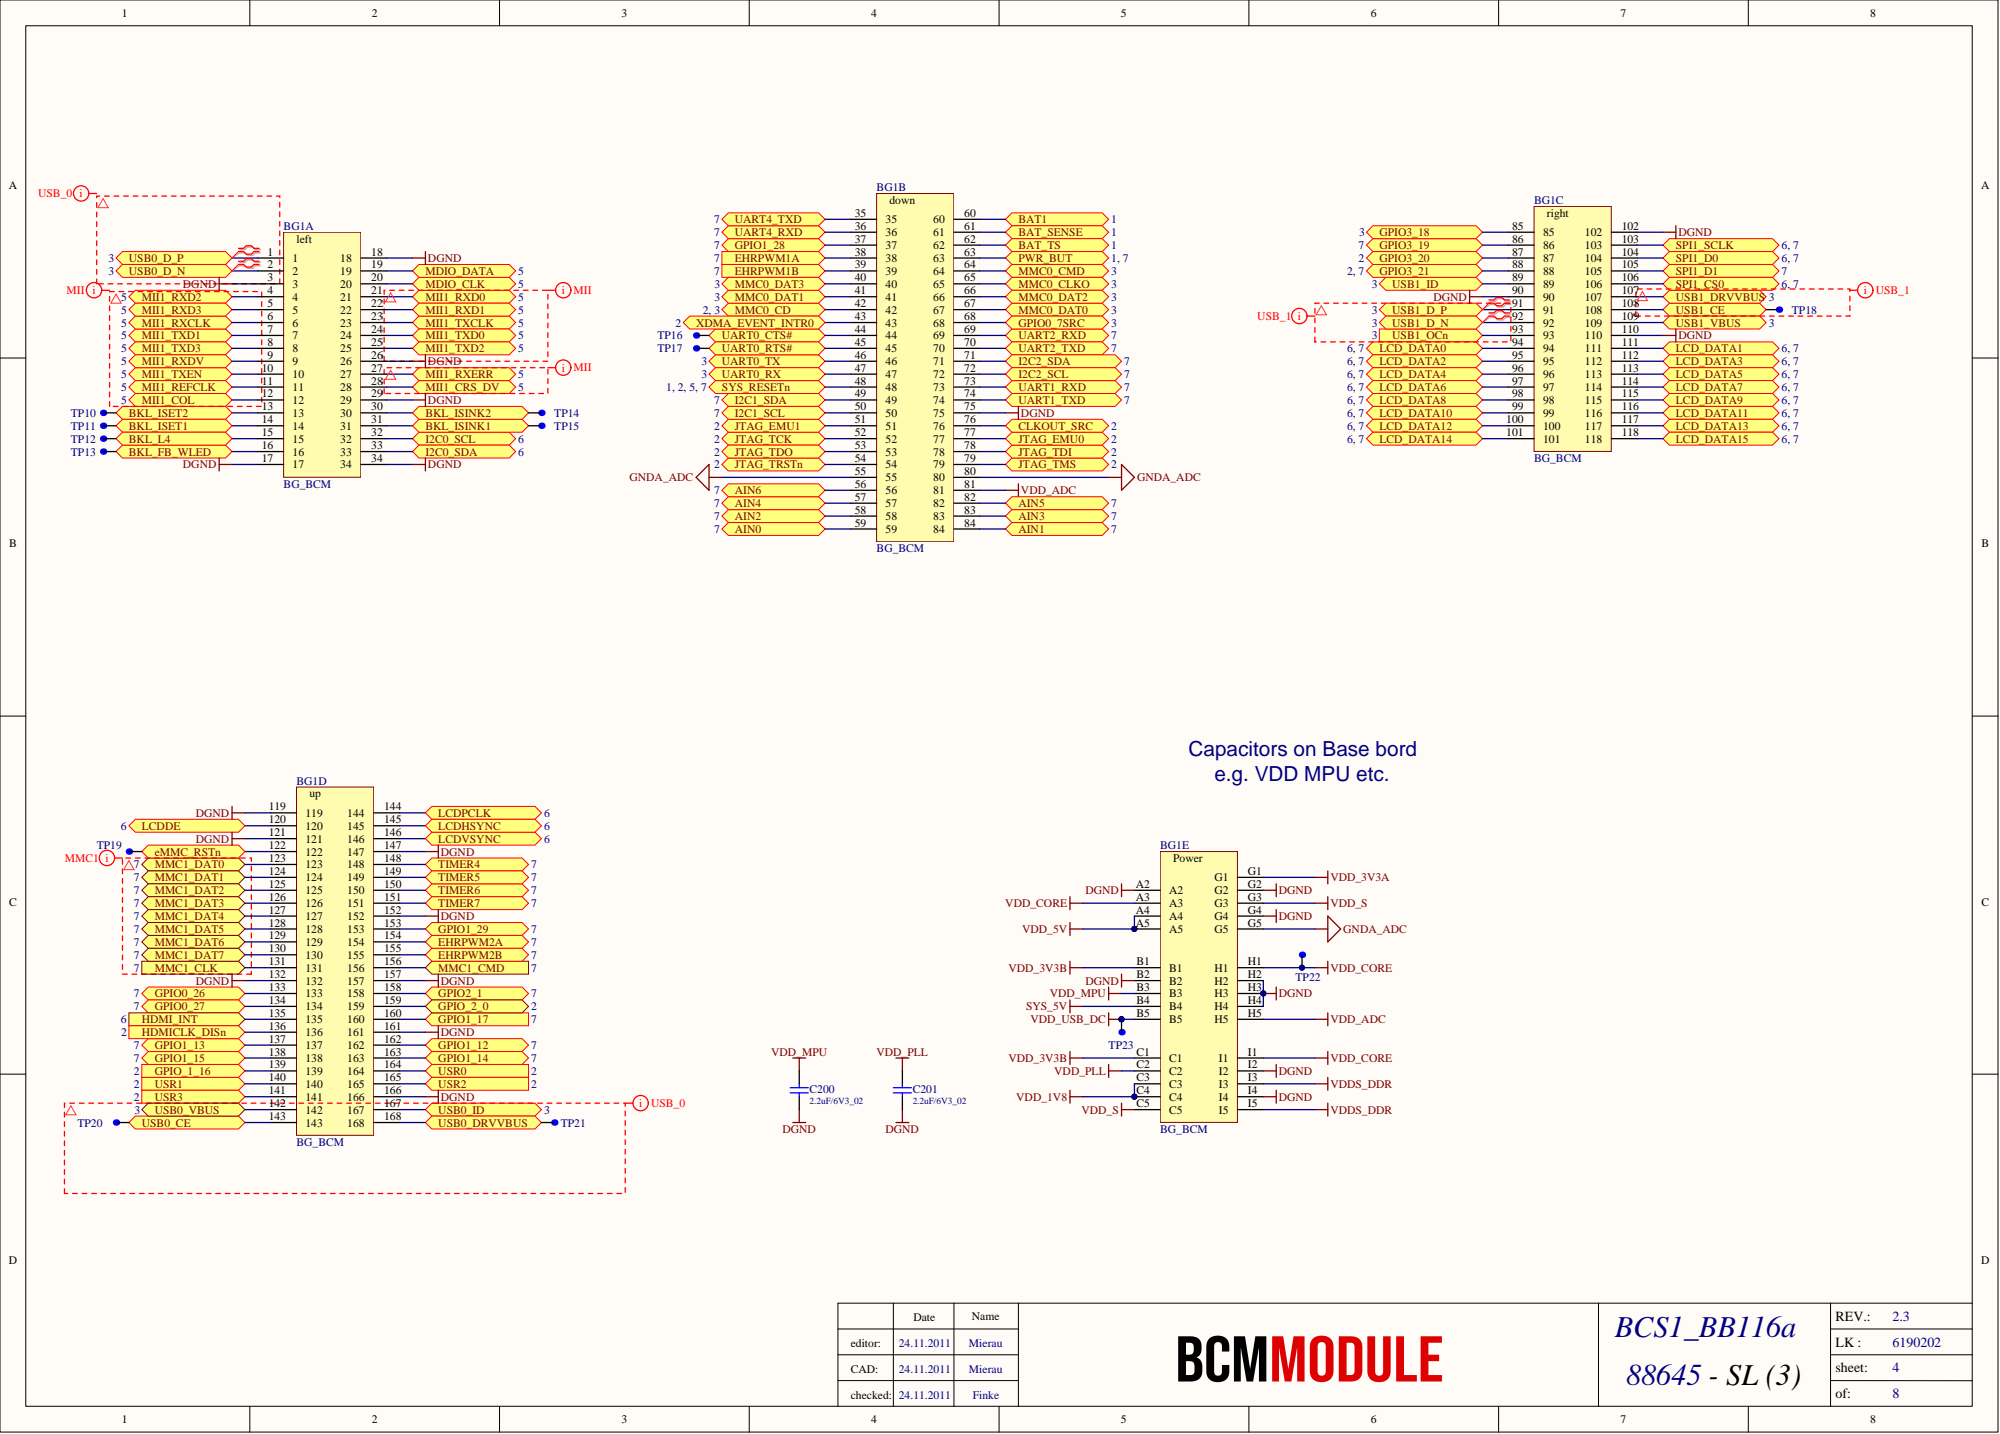
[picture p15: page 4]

Capacitors on Base bord
e.g. VDD MPU etc.

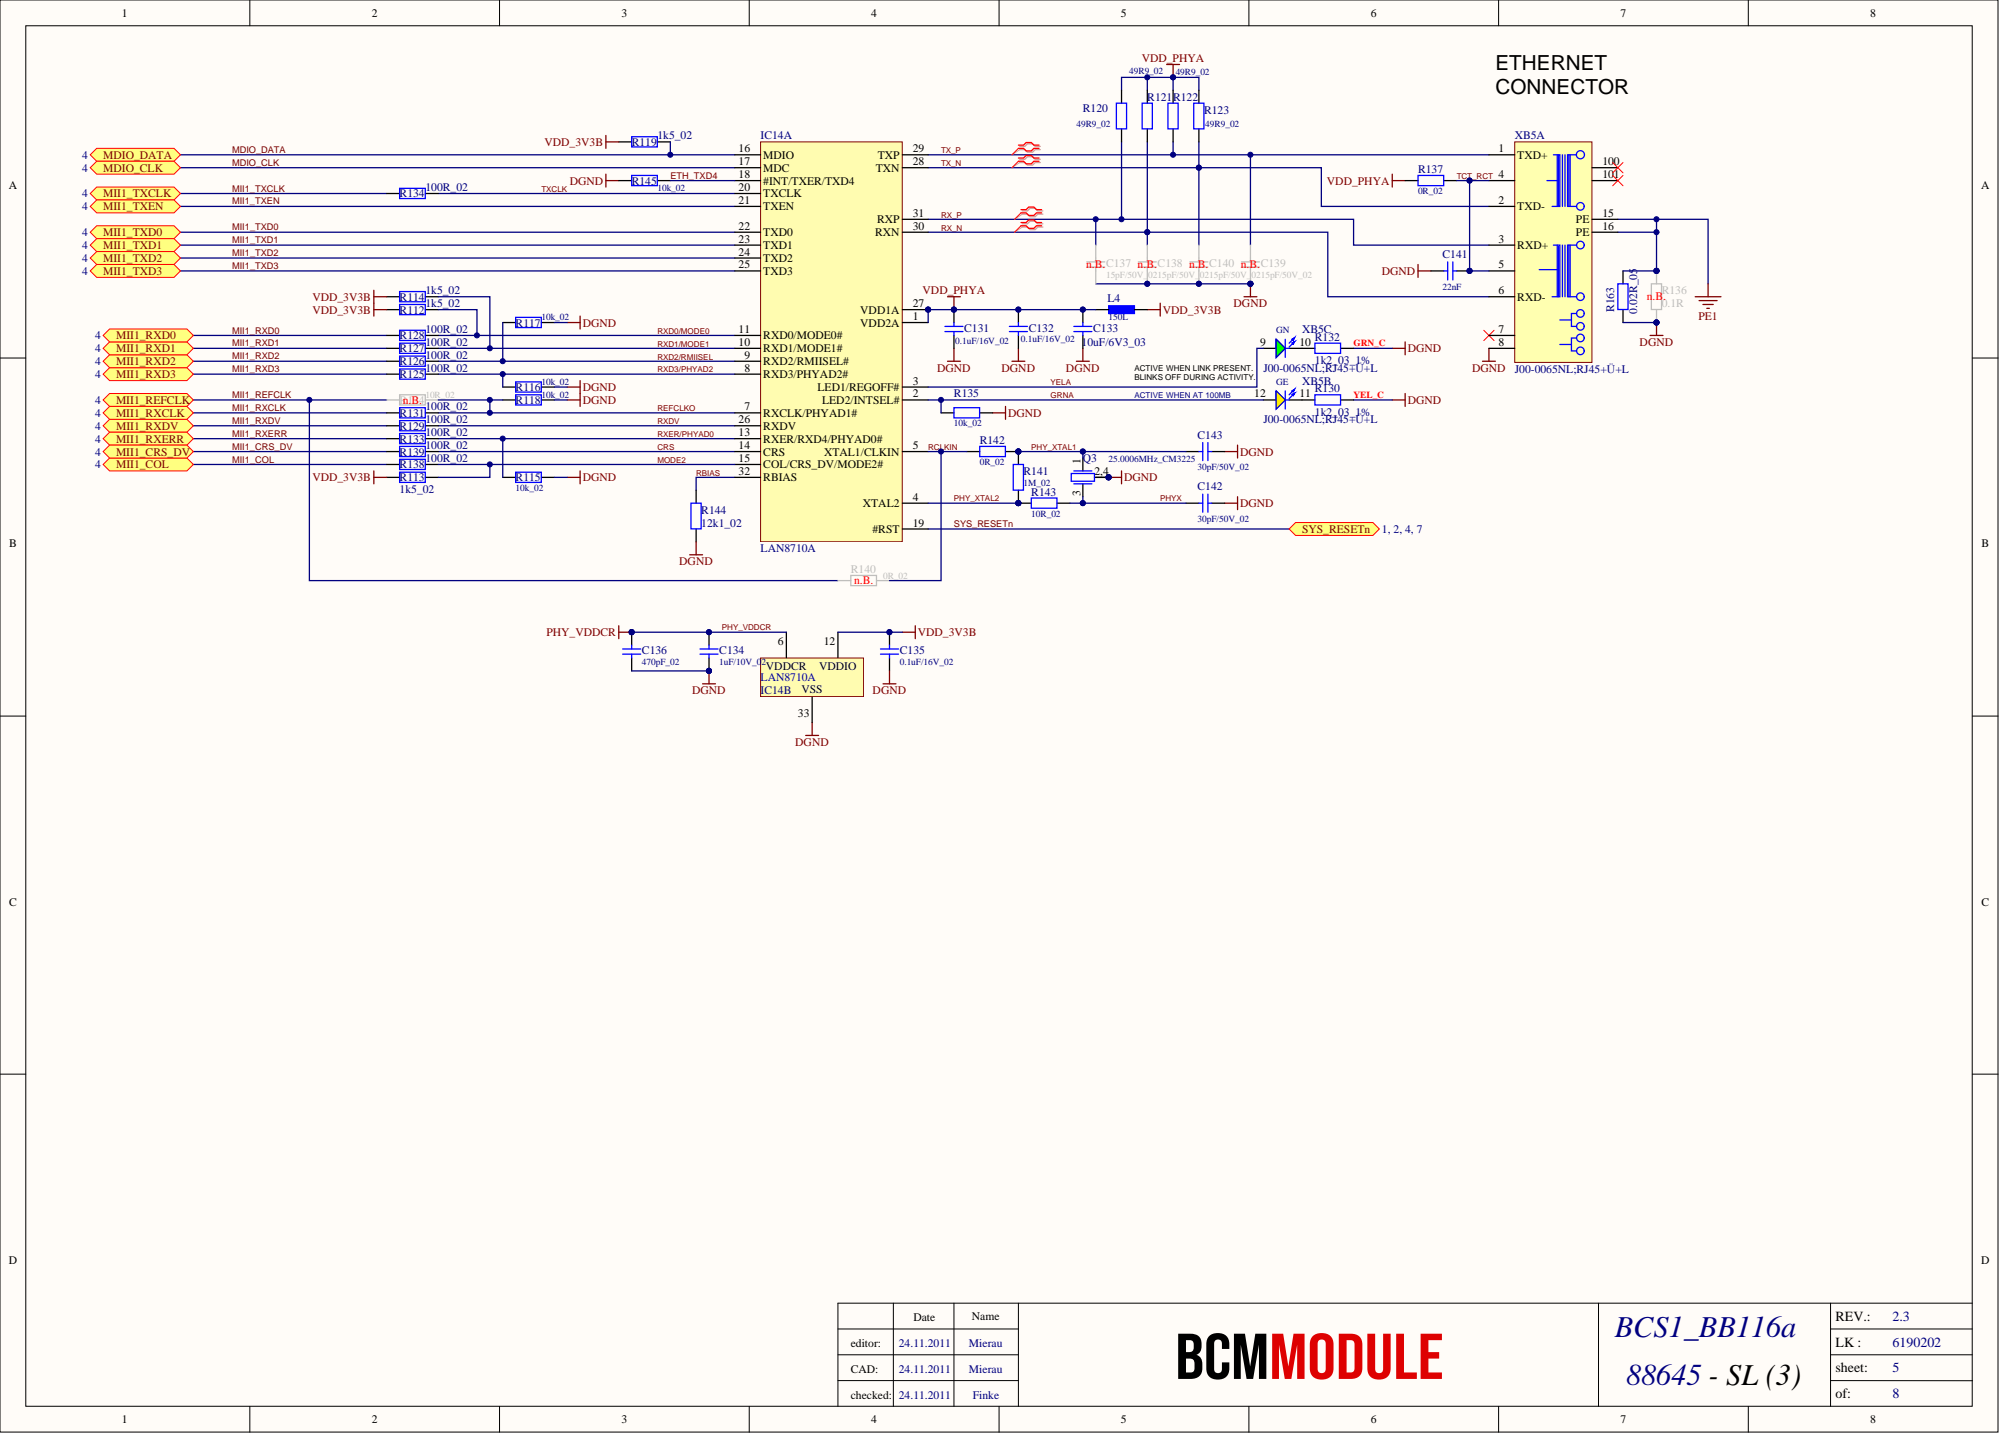
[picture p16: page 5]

RXD1/MODE1 | RXD2/RMIISEL# 9 RXD1/MODE1# 10 RXD0/MODE0# 11

ACTIVE WHEN LINK PRESENT.
BLINKS OFF DURING ACTIVITY.

CRS 14

MODE2 | COL/CRS_DV/MODE2# 15

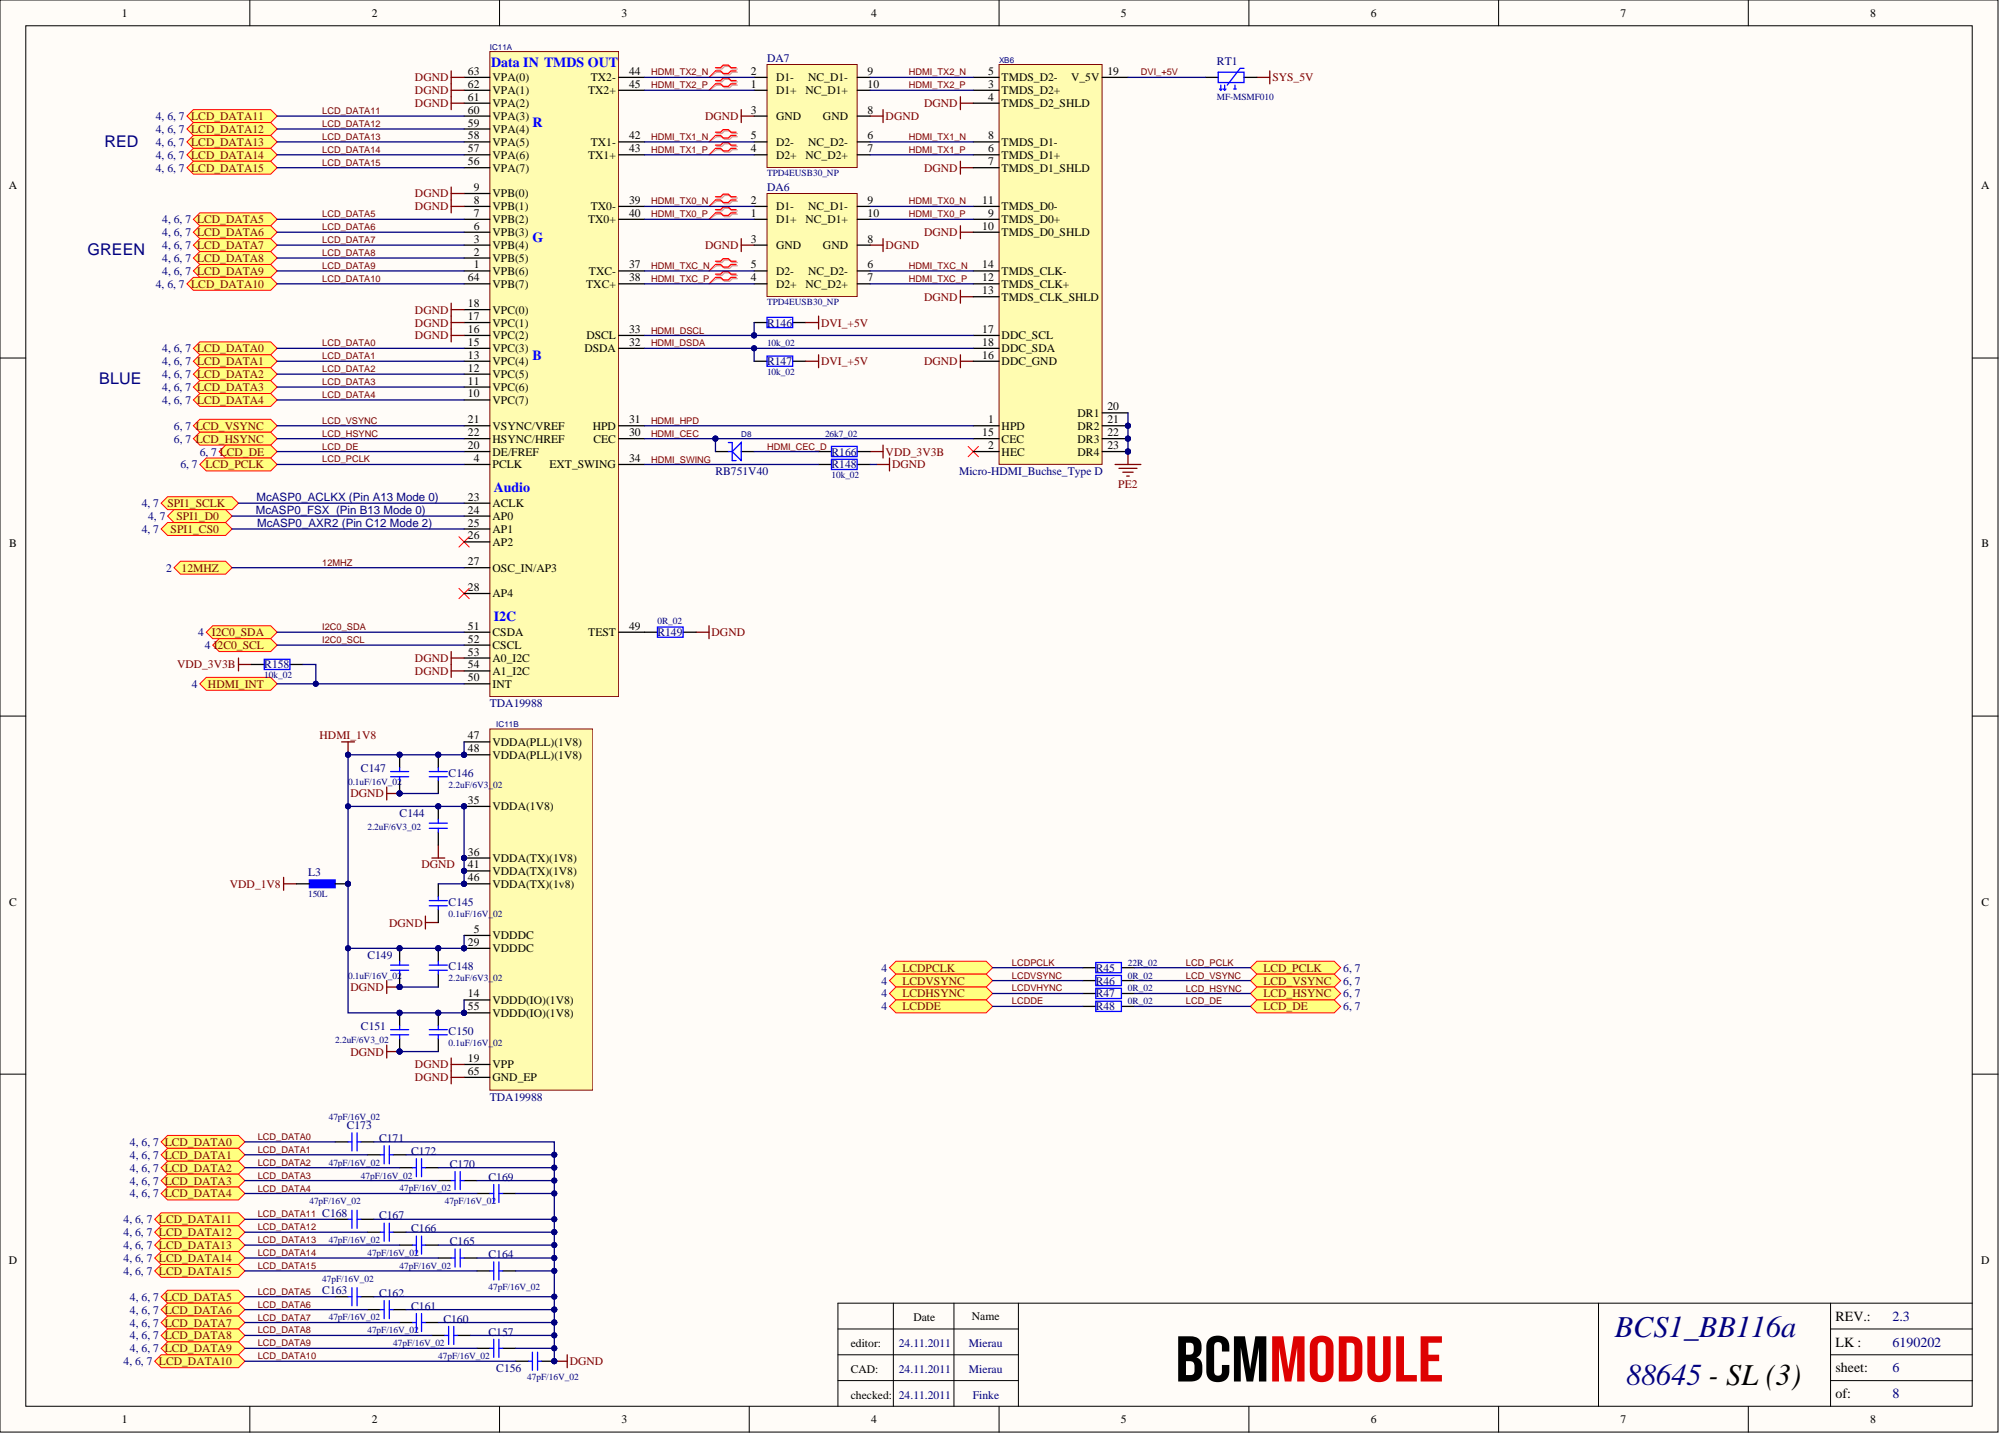
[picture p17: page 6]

VPA(6) 57 VPA(5) 58 VPA(4) 59 VPA(3) 60 VPA(2) 61 VPA(1) 62 VPA(0) 63 | HDMI_TX1_N | GND 3 | | HDMI_TX1_N | TMDS_D2_SHLD 4

HDMI_TX1_P | | HDMI_TX1_P | | TMDS_D1+ 6

HDMI_TXC_N | GND 3 | | HDMI_TXC_N | TMDS_D0_SHLD 10

HDMI_TXC_P | | HDMI_TXC_P | | TMDS_CLK+ 12

C146 | VDDA(1V8) 35

VDDA(TX)(1V8) 36

C148 | VDDD(IO)(1V8) 14

VPP 19

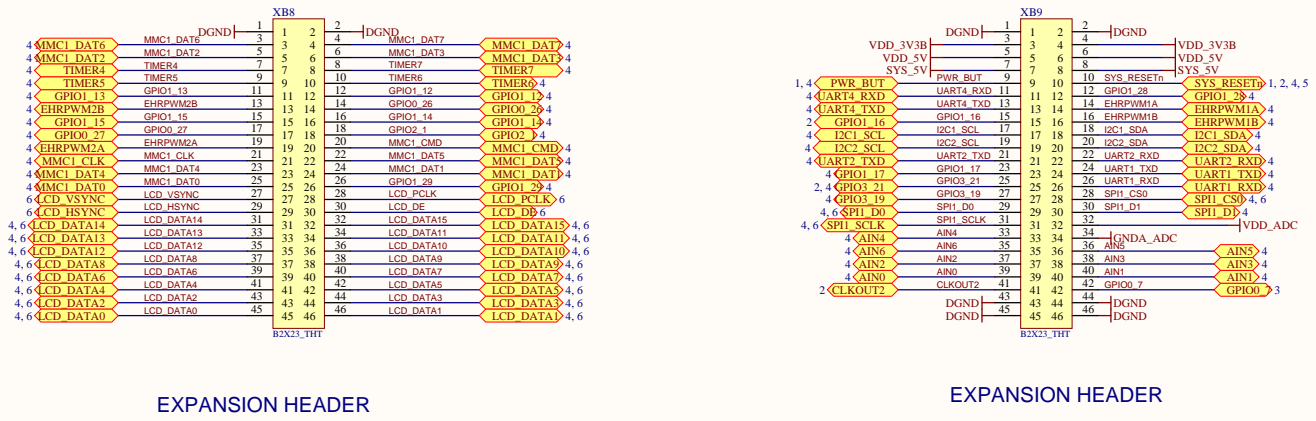
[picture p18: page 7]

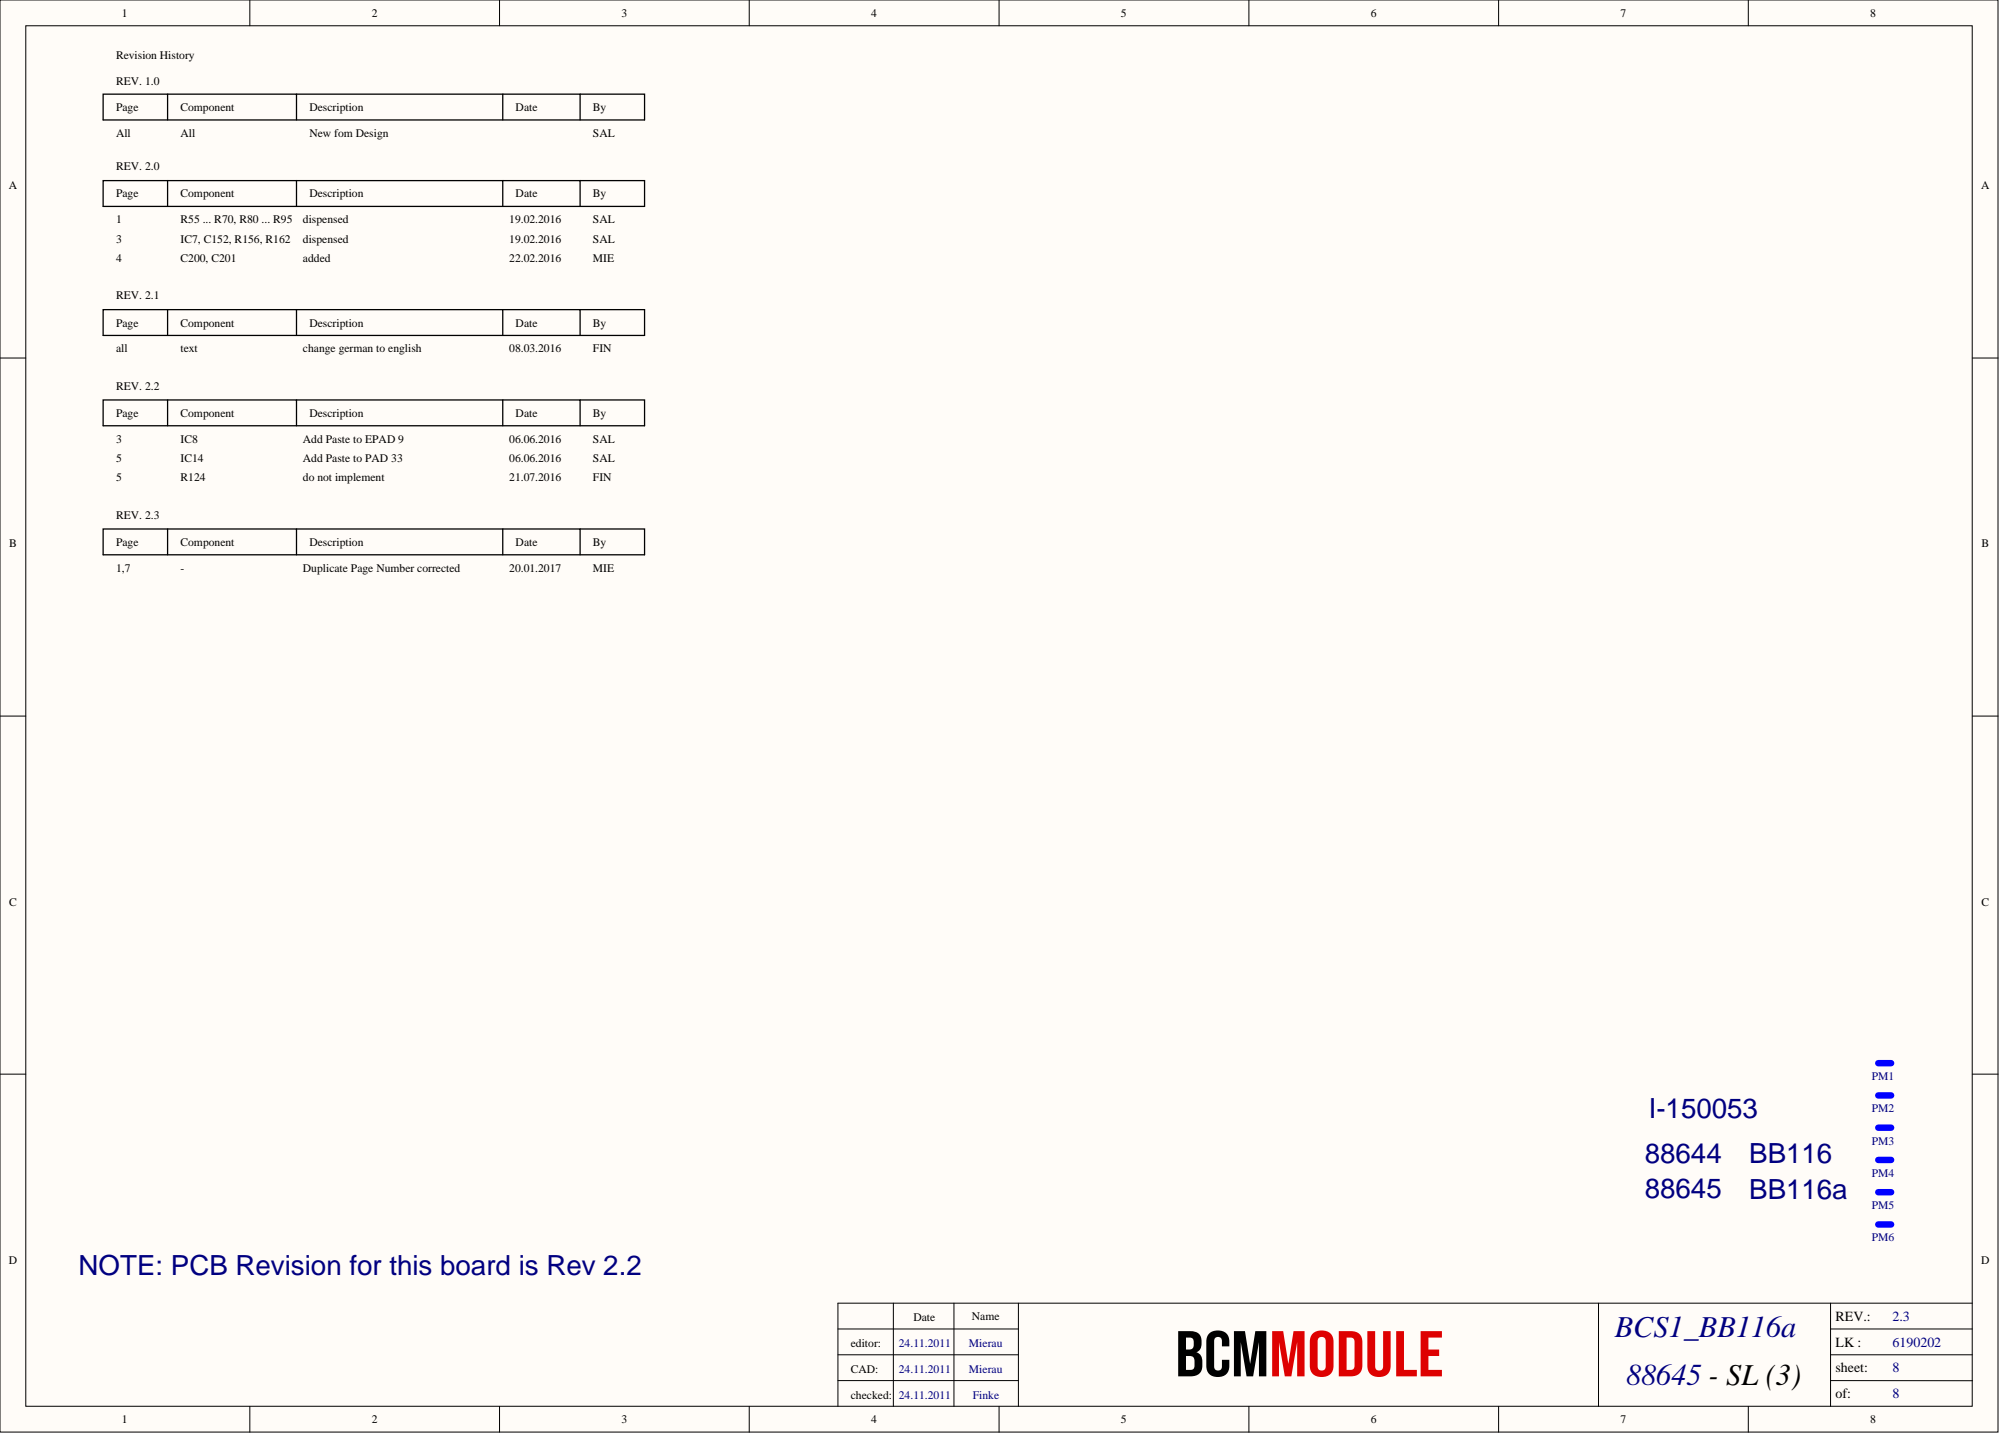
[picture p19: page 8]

NOTE: PCB Revision for this board is Rev 2.2

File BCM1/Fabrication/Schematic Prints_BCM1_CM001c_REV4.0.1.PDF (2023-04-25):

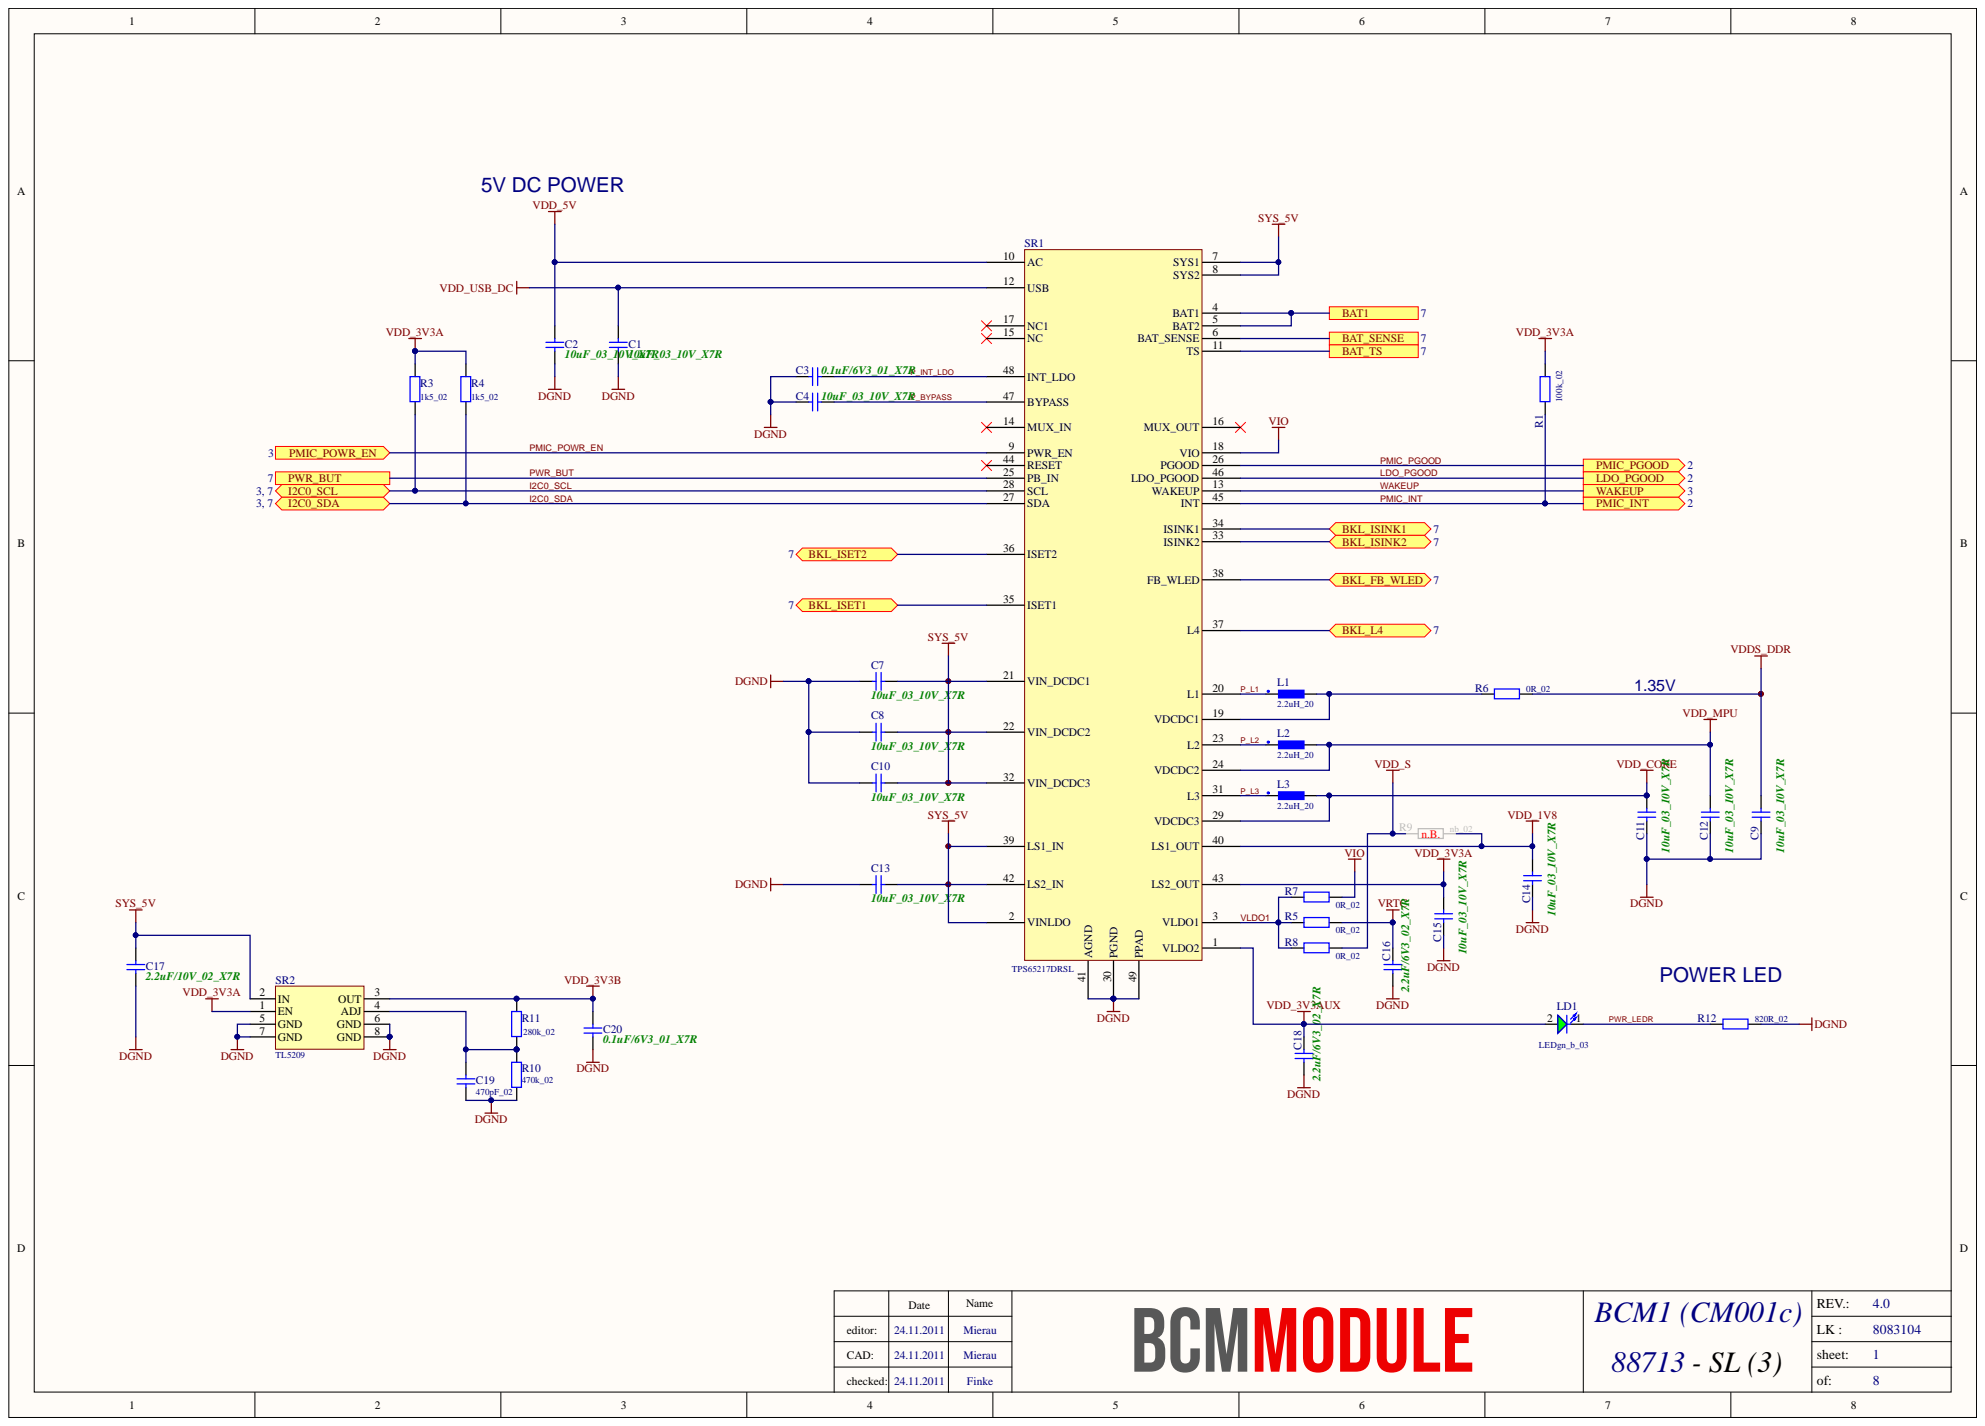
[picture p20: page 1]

PWR_BUT | RESET 44

PB_IN 25 | LDO_PGOOD

I2C0_SCL | SCL 28 | WAKEUP
I2C0_SDA | SDA 27 | PMIC_INT

R7 | | VRTC
R5 | 0R_02

editor: | Mierau

CAD: | Mierau

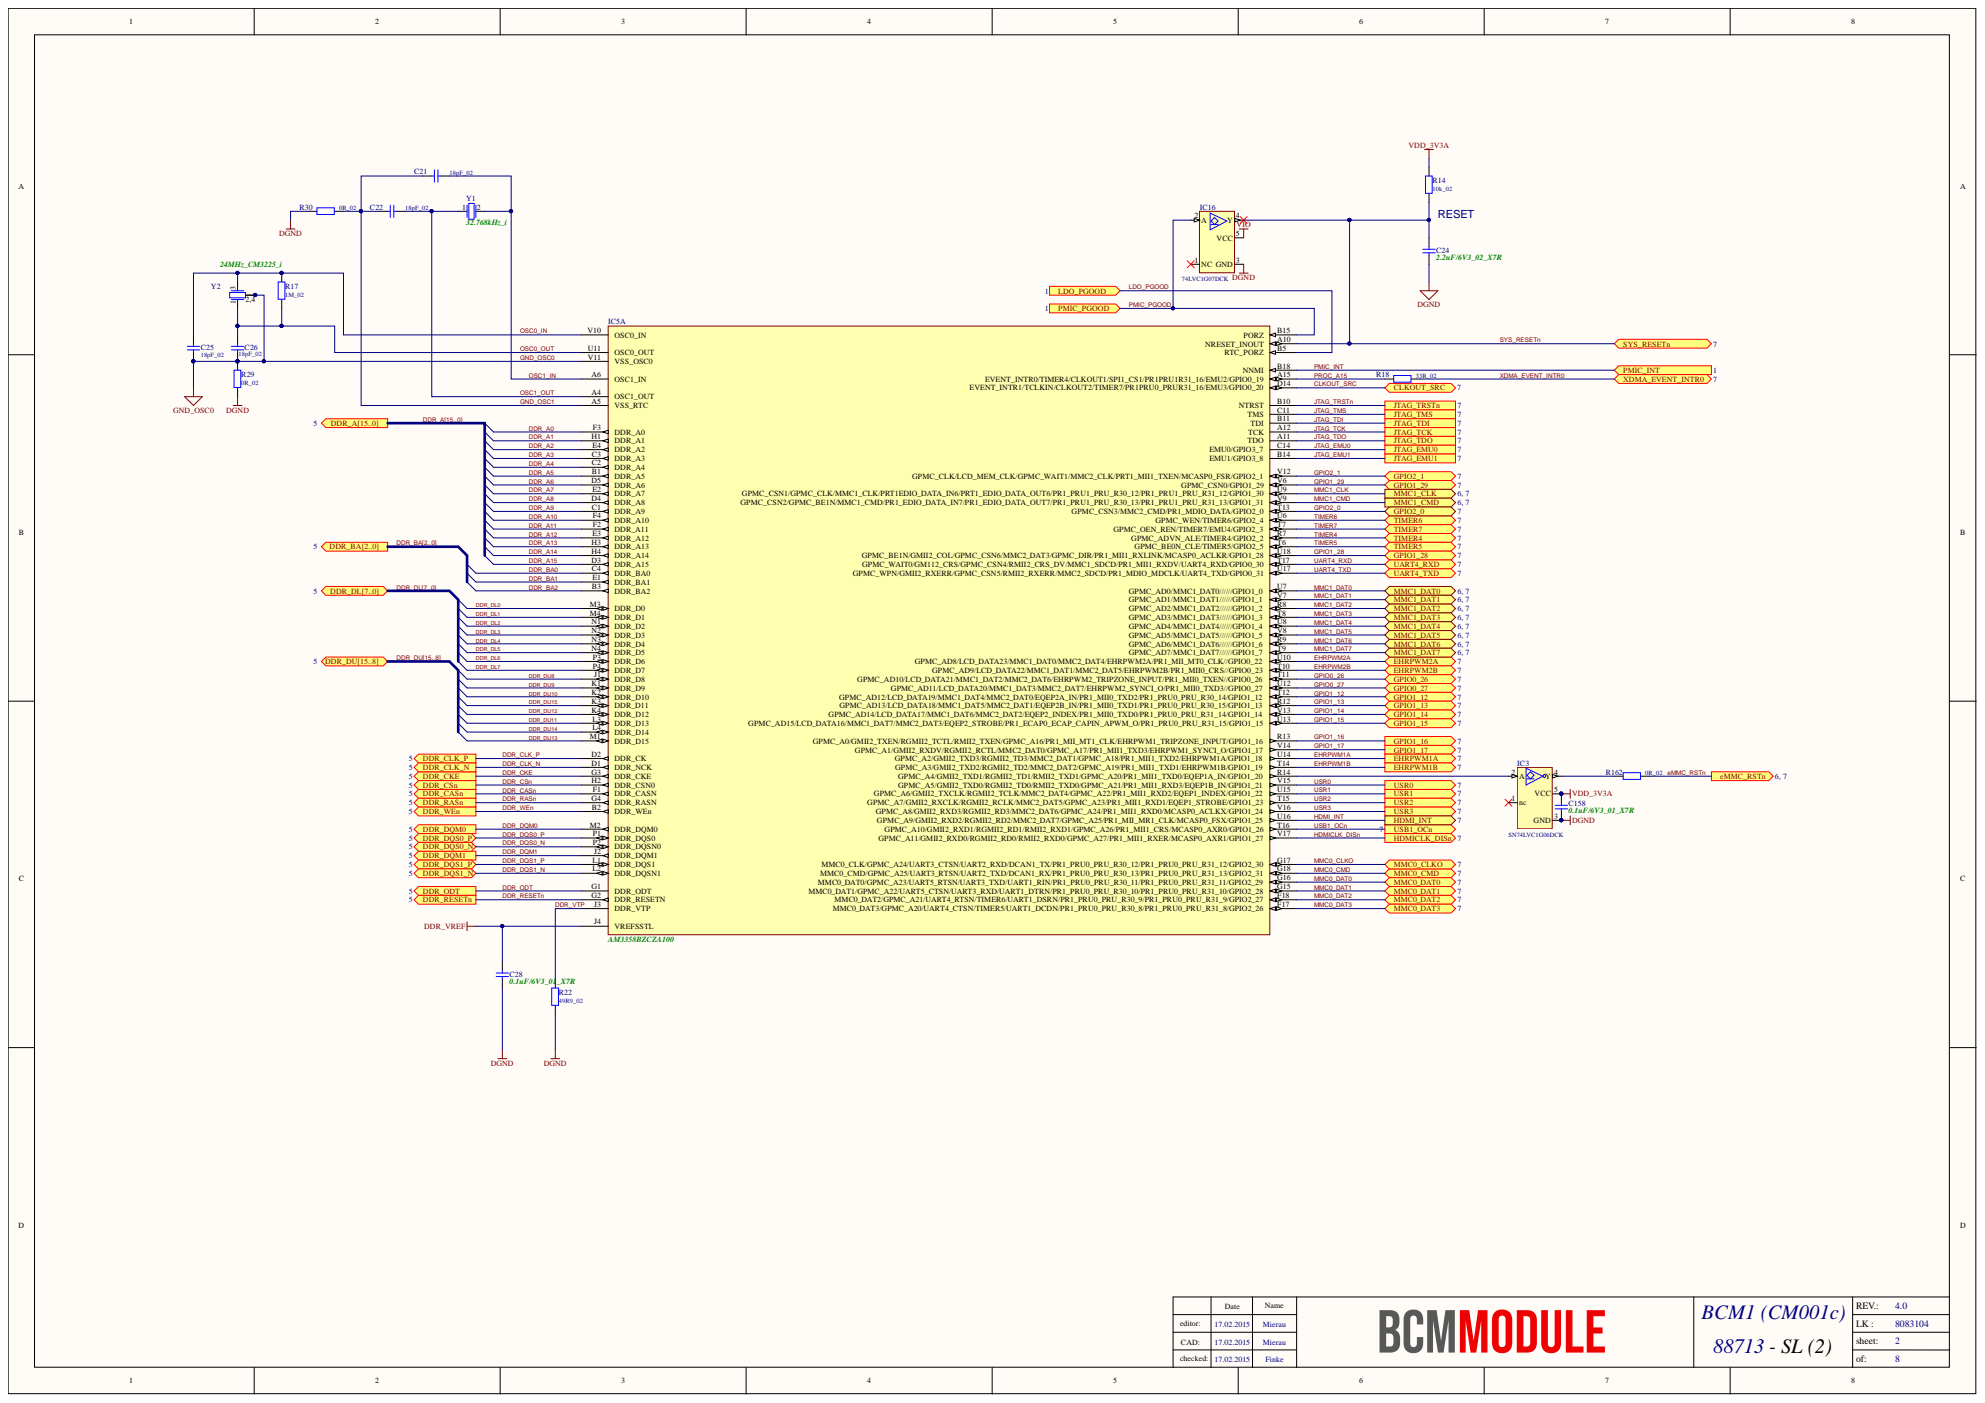
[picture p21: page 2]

OSC0_OUT | | OSC0_OUT U11 | NRESET_INOUT RTC_PORZ | A10 B5

GND_OSC0 | | VSS_OSC0 V11

OSC1_IN | | OSC1_IN A6

editor: | | Mierau


LCD_DATA0

LCD_DATA2
LCD_DATA3
LCD_DATA4

LCD_DATA6
LCD_DATA7

LCD_DATA9
LCD_DATA10
LCD_DATA11
LCD_DATA12
LCD_DATA13
LCD_DATA14
LCD_DATA15

editor: | | Mierau


VDD_MPU2 F11

VDD_MPU6 H13

VDD_MPU4 F13

150L | | VDDS_SRAM_MPU_BB D10

VDDS_PLL_MPU H15

CAP_VDD_SRAM_MPU | CAP_VBB_MPU C10 CAP_VDD_SRAM_MPU D11

CAP_VBB_MPU

VDDS_SRAM_CORE_BG E9 VDDA3P3V_USB0 N15 VDDA1P8V_USB0 N16

VSSA_USB M14

VDDA3P3V_USB1 R15

VDDS_DDR G5 | VDD_RTC
VDDS_DDR H5 | | ENZ_KALDO_1P8V
VDDS_DDR J5 | | TESTOUT

editor: | | Mierau


CK J7
CKn K7
CKE K9


VSS N5 VSS K8 VSS H10 VSS E7 VSS G5 VSSQ C4 VSSQ P4 VSSQ P6 VSSQ N2

VCCQ M4 VCCQ C6 VCCQ N4 VCCQ P5 VCCQ P3 VCC E6 VCC F5 VCC K9 VCC J10



alternatively added: IM4G16D3FABG-125 or NT5CC256M16DP-DI

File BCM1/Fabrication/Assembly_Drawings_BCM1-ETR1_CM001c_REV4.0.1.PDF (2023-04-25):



pni,,.., JU ,01 oo•lq 1

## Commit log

2016-03-04 [add] initial commit for BCM1 and BCS1 containing Assembly Drawings, BOM, Footprint Drawing, Gerber files, Schematics as well as Test Summary and Document Revision History
2016-03-07 [add] step files for BCM1 [add] Altium library for BCM1 [add] New Document Revision History (BeagleCore_Document_Revision_History_REV1.1.pdf) [del] Document Revision History (updated version has been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
    [CM001_REV2.0.step]
2016-07-11 [mod] updated footprint drawing (rev 2.2) [mod] new document history revision (rev 1.2)
2016-07-28 Updated to Revision 2.2
    [BOM_ BCS1_BB116a_REV2.2.xls]
2016-08-29 relocation & Altium files
    [BCS1_REV2.2.PrjPcb, BOM_ BCS1_BB116a_REV2.2.xls, CM001_REV2.0.step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]
2016-10-06 Added soldering profile for BCM1
2017-01-20 [mod] Updated Schematic Prints for BCS1 to revision 2.3 (no hardware related changes)
2017-08-14 FAQ: inserted correct link
2017-08-17 Published BOM for BCM1.ETR and changed naming from BCM1 only to .STR and .ETR for BOM
2018-12-03 Replace BOM v2.2 for BCM1.ETR with BOM v4.0
2018-12-03 Corrected file-ending for BOM BCM1.STR v2.2
2019-06-17 relocation files & add rev4
    [BCM1_CM001_REV2.0.step, BCM1_CM001_REV4.0.step]
2019-06-17 add new structure to project
    add tag rev2.2
    [BCM1_CM001_REV2.0.step, BCM1_CM001_REV4.0.step]
2019-06-17 add rev4.0
    add tag rev4.0
    [BCM1_CM001_REV2.0.step, BCM1_CM001_REV4.0.step]
